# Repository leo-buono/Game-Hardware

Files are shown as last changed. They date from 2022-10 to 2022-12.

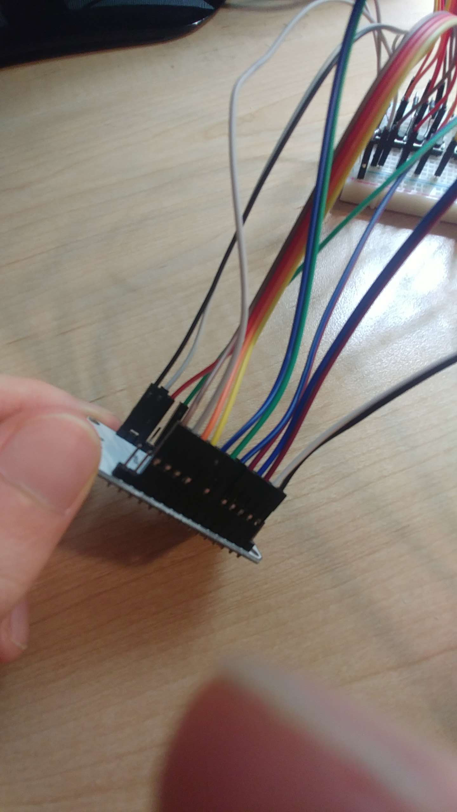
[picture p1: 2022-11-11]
Assignment 3/Images of Device and Electronics/Electronics 2.jpg

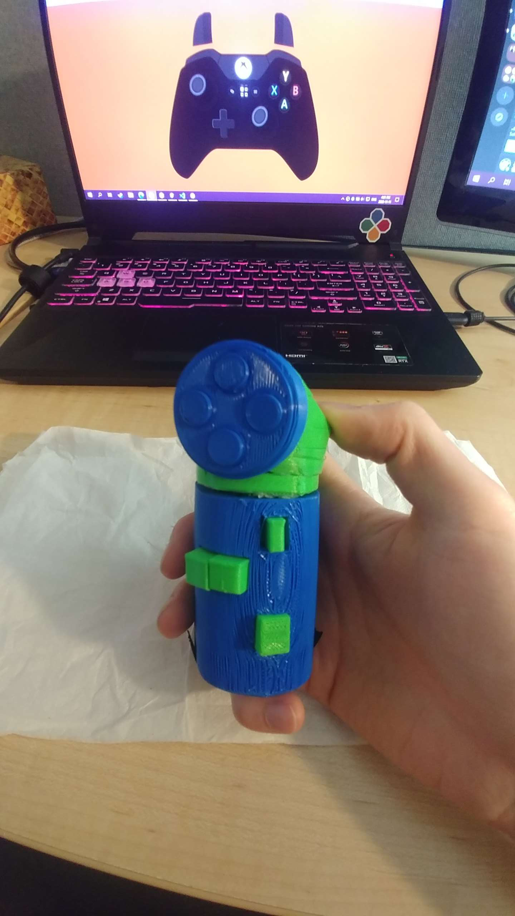
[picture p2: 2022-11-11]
Assignment 3/Images of Device and Electronics/3D Print 1.jpg

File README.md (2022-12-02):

# Game-Hardware
For the purpose of Game Hardware course at OTU (Team Name - SoftWhere?)

**Members & Roles:**   
1. Jonathan Jay - 100743575   
   - Prototyper 
2. Matthew McPherson - 100757379 
   - Designer  
3. Léo Buono - 100748457  
   - Programmer  

**Contributions:**    
     Jonathan Jay:           Created test Unity program, prepared model in slicer, created technical drawings and exploded view animation, QFD and SUS Analysis, and constructed controller.           
     Matthew McPherson:    Catalogued all information about the controllers develeopment, created pitch presentation, constructed controller, wrote report, and general support and design advice.   
     Léo Buono:            3D printed model, programmed micro controller, wrote literature review, QFD and SUS Analysis, soldered and constructed controller.  

**Progression:**   
Final iteration has been created, 3D printed and constructed.    

**Videos**  
Final Project Overview: https://youtu.be/Jnym4vkfmT4  
Exploded View: https://youtu.be/CayruH1D1og  
Assembley: https://youtu.be/mAC65vVBCyk  

**Past Assignment ReadMe Archive**  

**Assignment 3 ReadMe Archive:**     
    
**Contributions:**    
     Jonathan Jay:           Created test Unity program, prepared model in slicer and constructed controller.           
     Matthew McPherson:    Catalogued all information about the controllers develeopment, created pressentation focusing on iteration, and general support and design advice.   
         (would have helped with construction but was unable to due to the Go Bus strike making commuting to campus impossible).    
     Léo Buono:            3D printed model, programmed micro controller and constructed controller.      
 
 **Progression:**   
First 3D print has been created and most functions have been programmed and wired.    
Print Details:  
Grip Print: ~6 hours; 39g blue PLA  
Everything else: (printed with a raft) ~6 hours; 42g green PLA  
  
(14 minute video because of no listed time limit on assignment outline)  
Project Progression Video: https://youtu.be/8G_iirl803k  

**Trello (as of Assignment 3):**  
https://trello.com/b/S6caR4iL/softwhere  
Trello 3
  
**In the Assignment 3 folder you will find:**  
- Images of our 3D print and electronic components  
- Video folder containing Slicer animations and youtube links to said animations  
- A folder containing the 3D print files  
- A folder containing our interactive scene, which is also playable on the github pages (readme there for more details)

**Assignment 2 ReadMe Archive:**  

Contributions:  
     Jonathan Jay:        CAD model, Electronic Schematics  
     Matthew McPherson:   Electronic Schematics, Components List, GrabCAD model search  
     Léo Buono:           Electronic Schematics, Components List, GrabCAD model search  
     
Progress:  
     The project has completed CAD models and is ready to begin physical prototyping via 3D printing. In addition, the project is also entering the phase where we are programming the microcontroller and using breadboard to test components.

In the Assignment 2 folder, you will find:  
-The step file for our controller  
-The technical drawings for our controller and each components  
-A folder called "Schematics" containing our circuit schematics  
-A folder called "Components list" containing a pdf of our component list for electronics  

Notes:  
While creating the exploded view, we ran into issues because we were using Sub-assemblies, and those don't count as extra components and we don't know how to make them do so. This led to us having to un-subassembly all our components which broke our exploding animation. We also found out that all our components' positions are baked into them, which means the technical drawings are not at the correct angle, we didn't know how to fix it so left it as it.

Video Link for Assignment 2 - https://youtu.be/B3a3DfTxIls  

GrabCAD Links:  
https://grabcad.com/library/slide-potentiometers-1  
https://grabcad.com/library/tactile-switches-6mm-tht-1  
https://grabcad.com/library/xbox-one-analog-stick-assembly-1  
https://grabcad.com/library/esp32-devkitc-v4-1

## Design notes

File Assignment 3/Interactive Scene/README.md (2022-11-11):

This Interactive scene is for the purpose of showcasing the functionality of our one handed controller.  
Added through github pages: https://leo-buono.github.io/Game-Hardware/  

In this scene you take control of a character who can move, jump and shoot.  
The goal is to jump from platform to platform without falling and loop around the path. There's also some black boxes along the way that you can use to practice shooting (not required).  
  
Win Condition: make it to the top of the structure.  
Lose condition: fall of the ledge, leads to restart.  
  
Controls:  
Left Stick/WASD - move    
Right Stick/Mouse - aim/move camera    
Left Trigger/Right Mouse - aim mode  
Right Trigger/Left Mouse - shoot  
A/Space - jump

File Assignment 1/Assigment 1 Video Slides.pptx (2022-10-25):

## One-Handed Controller By: SoftWhere

Jonathan Jay - 100743575
Matthew McPherson - 100757379
Léo Buono - 100748457

## Product Description

- We intend to create a one-handed video game controller
- This controller will allow people to use all the same inputs as a standard controller has (2 joysticks, 4 face buttons, d-pad, 2 bumpers, 2 triggers, and start and select), while only requiring one hand to use.
- The goal is to improve the player experience and make it easier to play compared to an able-bodied person.

## Design Thinking Process

## Interview and Digging Deeper

- We interviewed 6 people about their history of using one-handed controllers and what they expected from them.
- All had used a wii-remote and some had used VR controllers.
- Positive over all opinions but criticize the lack of compatibility with all games.
- The interviewees all thought that a one-handed controller should be comfortable and ergonomic.
- Also thought that every part of the controller should be easy to reach without straining your hand

## Reframe the Problem

- We researched past one-handed controllers to gain ideas on how our design could improve on them.
Product Comparison
- There have been many designs in the past:
  - One-handed RPG controller for the NES
  - One-handed controllers with remappable back triggers for ps1
  - One-handed controller with shift button to swap joystick functionality for ps3
  - Various 3D printed snap-on adapters for many controller types
  - Xbox adaptive controller

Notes: Such as joycon merger

## Ideate

- After brainstorming, we came up with 3 ideas:
  - Controller with one joystick that can be shifted using a layout shift button. It will also have 4 face buttons (a,b,x,y), 2 bumpers, 2 triggers, and the shift button on the back of the controller.
  - The use of Gyro to replace one of the analog sticks, removing the need for a second thumb and allowing for both sticks to be in use. Combined with an activation button, (hand, feet, or palm etc.) it can be disabled not requiring the user to keep their hands perfectly still, and this could be used as a recenter button for the Gyro.
  - Utilising a ‘Squeeze’ input. This allows the user to push with their palm in order to give the input. Using this with layout shifting, you’re able to quickly press any combination of buttons, and keep all fingers available for the inputs, as opposed to having a finger dedicated to shifting. There would also be a strap to hold the controller against the upper palm.

## Feedback

- Some feature from our designs were presented to our interviewees for feedback, and 3 we went into discussion with:
  - Turbo Buttons: widely considered helpful, but could affect the play experience.
  - Gyro: potentially helpful but tricky to get right.
  - Shift button: very positively received, but some concern over control complexity.
  - Pedals: potentially useful but unnecessary, problems with wiring to the controller itself (why not go to computer directly).
  - Palm Grip: not well received due to players potentially squeezing the grip unintentionally during tense gameplay moments and un-intuitiveness.

## Final Idea

- The idea that we will be implementing is a controller that will be strapped to your upper palm to allow the usage of every finger. To strap it on, a gear to tighten and loosen the strap will be on the side (see sketch below).
- The buttons on the controller will be as follows:
- Four face buttons on index finger
- Tilt button for bumpers on the middle finger
- Individual triggers on the ring finger
- Layout shift Button on the pinkie finger
- Joystick on the thumb
- Two Menu buttons

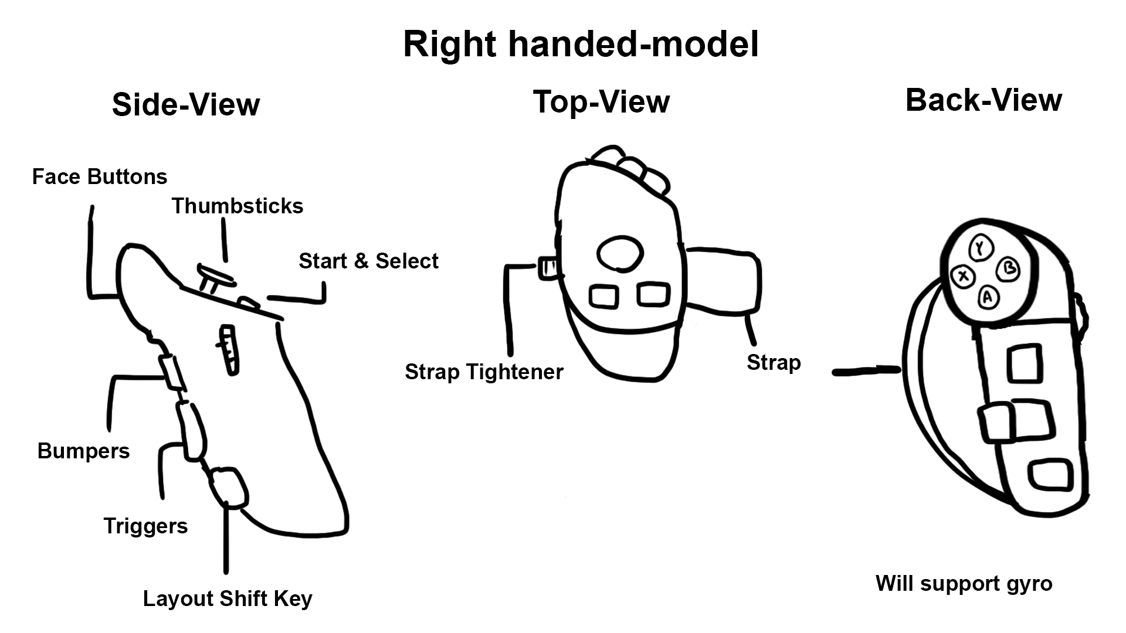
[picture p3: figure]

## Planning

## Planning

- We will be using a trello board to keep track of all tasks

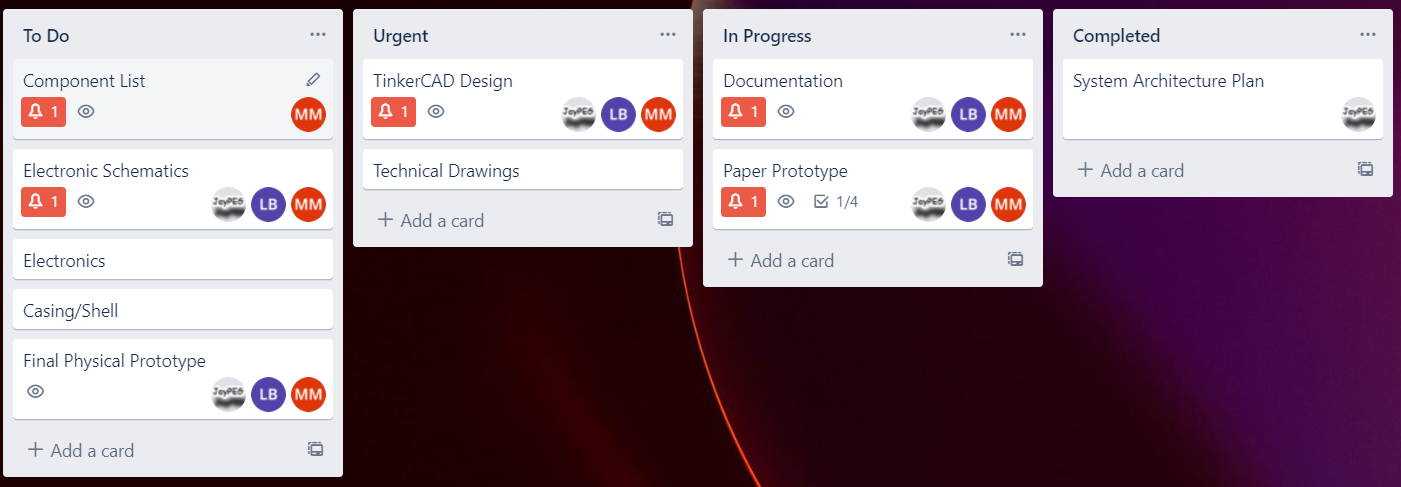
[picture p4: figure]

## The End

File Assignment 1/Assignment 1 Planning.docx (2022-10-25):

- Project description, problem definition:

Context: Playing video games is an activity that can require a wider range of mobility thanks to various controller types like Xbox controllers, or Racing wheels enhancing player experiences.

Issues: However, not all people, and not all players have the physical capability to fully utilise the input device to its fullest potential.

Relevance: This can cause players to struggle to play certain games, and in certain cases make it impossible or nearly impossible to play the desired game using traditional input devices.

Objective: In this project we will be constructing a controller with an aim to allow players with more limited motor functionality to play more of these games that were previously inaccessible, and improve their experiences playing games they may have previously struggled with.

Existing solutions: There are a number of ways that can be implemented to solve the accessibility problem, and there are various available on the market today, such as the Gypard, and many 3D print options such as one where it makes one of the analog sticks accessible in the rear of the controller.

https://gypard.com/

https://www.notebookcheck.net/3D-printed-PlayStation-controller-mod-allows-one-handed-PS4-and-PS5-gaming.597669.0.html

To ask about how viable out ideas are, we asked 6 people some questions:

Questions:

Have you ever used a one-handed controller before (wii remote, vr controller)?

What do you expect from a one-handed controller?

Here are some ideas: etc.

We also engaged in discussions with a few of them:

Pedals sound good, tho consider, Mouth controller (blowtubes https://www.quadstick.com/)

Extra latency

Palm grip: though how do you put it on, wrist as alternative

Turbo does have effect an effect on the game experience

Layout Shift button - only some keys, gyro enable and disable?

Context stuff

Project Description

Definition

Playing video games is an activity that can require a wider range of mobility thanks to the various controller types, like Xbox controllers or Racing wheels, that enhance player experiences. However, not all people, and not all players have the physical capability to fully utilise the input device to its fullest potential. This can result in these players unable to enjoy and play certain games, and in some cases make it impossible or nearly impossible to play the desired game using traditional input devices.

There are a number of tools that can be utilized to mitigate the problem, and various are available on the market today, such as the Gypard and multiple 3D print options, like one that connects one of the analog sticks to another on the rear of the controller, allowing the player to use any surface, such as their thigh to operate one of the analog sticks.

The techniques others have come up with to increase usability are diverse, and include making the controller hardware customizable, like with the Xbox Adaptive Controller and a patented flat controller concept (patent expired) that puts the various inputs within a finger’s reach. Both require being placed on a stable surface to be used properly though, and this makes them not very portable.

In this project, we will be constructing a controller with a goal to allow players with more limited motor functionality to play and enjoy more of the games that were previously inaccessible, and improve their experiences playing them. We will aim to create a handheld design so that people aren’t required to use a table or other flat surface.

Justification

If this problem is not solved, a number of people will remain unable to play and enjoy video games in a comfortable and fun manner. This problem affects people who cannot use two hands playing games that require two. They can be either born this way or lost the hand or function because of an accident.

This problem isn’t specific to just video games, accessibility is a topic discussed in most industries, and many people have attempted solutions in their specific contexts. Not only this, but statistics show that over 3 million people in the USA alone do not have 2 fully functioning hands, which shows just how large of a population could be encountering issues.This does mean that the market for tools that can be used with one hand become important. One example is the JoyKey, it attempts to create a one-handed keyboard for katakana by utilizing flick input keys (joysticks), it is also multipurpose and can be used as a controller (though not effectively one-handed). Another tool is an adaptor for two-handed instruments, such as one for a bass guitar that controls the frets using a foot controller, while allowing the musician to strum with their hand.

Ideation

Design Think

Interview & Digging deeper

We interviewed 6 people about using one-handed controllers. (see appendix for the questions asked)

All six interviewees had used a one-handed controller before, typically a Wii remote and a few had used a VR controller. All of them had positive things to say about the controllers, but criticized their lack of usability for all games. For example: the Wii remote is only one-handed in specific games/contexts. One person also noted that extended use of a one-handed controller can cause cramping.

When asked about what they expected out of a one-handed controller, all of the interviewees were very unanimous with their thoughts. All of them noted that it had to be comfortable to hold and ergonomic. They also thought that the buttons had to be easily accessible without having to reach or strain their hand to access vital controls.

The questions we asked were:

- Have you used a one-handed controller before (VR, Wiimote, etc.)? How did you feel about that experience?
- What do you expect from a one-handed controller?
- Some of the ideas we have for solutions regarding one-handed controllers include:
  - Shift button to reduce the number of total buttons
  - Attachments like foot pedals
  - Gyro to replace directional input
  - Utilizing your palm's grip for an input
  - Turbo and button lock systems
- What are your thoughts on our ideas?

Reframe the problem

Looking through the history of one-handed controllers, there were many different designs, approaches and intentions over the years. Some of the earliest ones were made for the Nintendo Famicom with the purpose of being used not for people with one hand, but rather for RPG games specifically. Much later, controllers were made with the sole purpose of accessibility and inclusion. In 1991, a controller was made for non-analog PS1 games that utilized remappable back buttons to make it more effective and customizable. In 2016, a controller was made that utilized a SHIFT button to swap what the joystick would do. It would cycle between the left stick, right stick and the d-pad. In more recent years, such as 2017, 3D printing your own snap on controller add-ons would become more widespread. This would make it easier to share ideas without the need to manufacture and sell them. In 2018, Microsoft would release the Xbox adaptive controller which was compatible with many other devices which allowed users to create their own set ups to suit their needs more specifically.

Ideate

To think of solutions, we discussed within our group and utilized our interview results and research to create these 3 concepts:

1) Controller with one joystick that can be shifted using a layout shift button. It will also have 4 face buttons (a,b,x,y), 2 bumpers, 2 triggers, and the shift button on the back of the controller.
2) Controller with one joystick and gyro that can be disabled through use of an external input (pedal, grip, etc.) to replace the other joystick. All the standard buttons would be on the back of the controller.
3) Controller with a squeeze input that would be used as a layout shift button, similar to idea 1 but with different button placement and a strap to keep the controller in the hand without requiring it to be gripped, making the input possible

Feedback

We then discussed with 3 of the interviewees their opinions of the features created above (see appendix for the list of potential features). The use of turbo buttons was widely considered useful. Gyro controls were thought to be useful, but to a point and difficult to perfect. The shift button was also thought to be useful but with some concern over complexity. The pedals were considered useful but a little unnecessary. No one really liked the palm grip as players may grip unintentionally during tense sections of games and it would be difficult to learn. Utilizing this feedback and previous information, we created a final concept.

Proposed Concept

The features that were deemed most important were considered when designing the controller.


As seen in Fig. 1, the controller utilizes a vertical grip shape and a strap to hold it against the upper palm, making it harder to drop. The strap is tightened using a gear on the side to make it easier to put on with one hand. At the top of the controller is a joystick and the two menu buttons, on the back is the rest of the inputs. Going downwards, there are the 4 face buttons, the 2 bumpers imputed through a single tilt button, the two triggers side by side, and the shift button that is held when layout shifting.

Layout shifting changes the face buttons into d-pad inputs and activate the gyro for right-stick

System Architecture

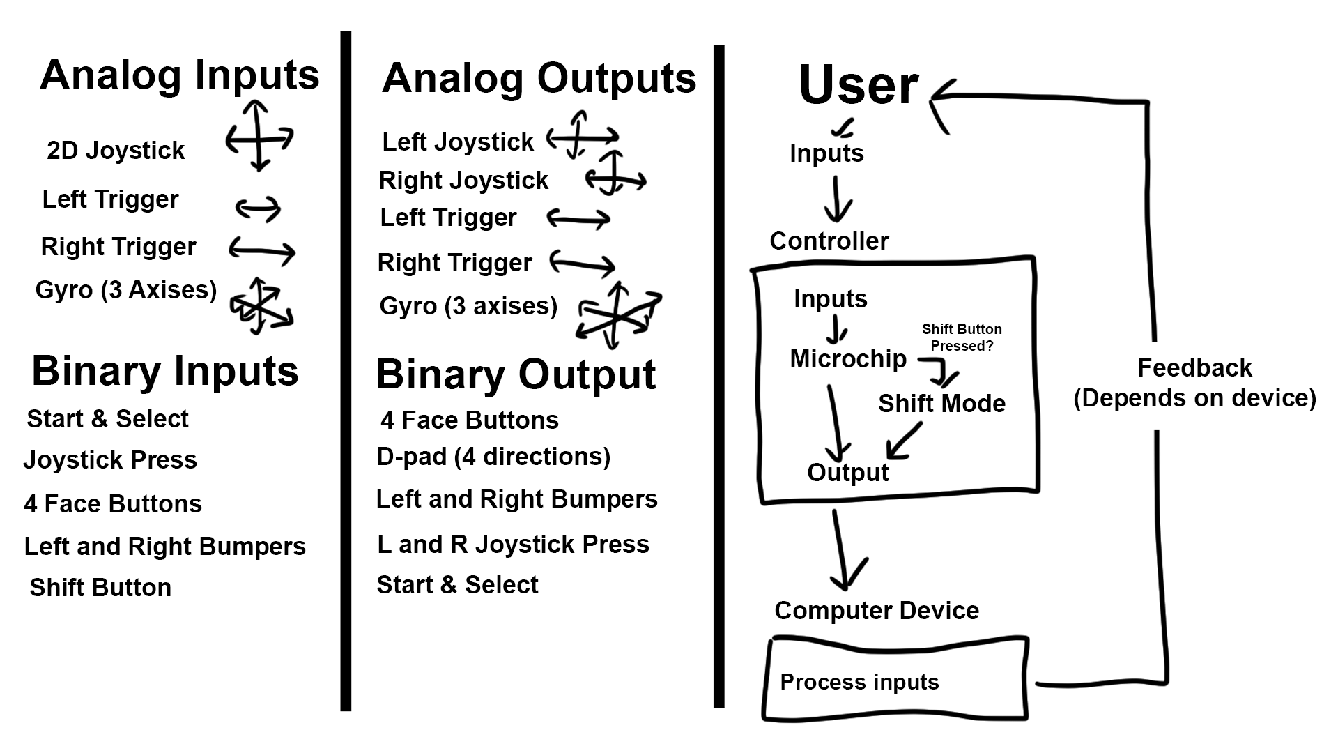
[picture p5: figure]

As seen in Fig. 2, our controller outputs computer readable controller inputs, and takes in less inputs that it outputs. The shift button is the reason for this and is what is used to decide how the other inputs are read and passed through to the computer. This extra step is what allows the controller to output more values than its inputs.

Product Comparison

Timeline of One Handed Controllers:

Source: https://www.oneswitch.org.uk/OS-REPOSITORY/MUSEUM/VARIOUS/CONTROLLERS/ONE-HANDED/ONE-HANDED-GAMING.pdf

1983: Nintendo Famicom Gamepad is created for one handed play.

1989: Ultech Mejin-kun one-hand joystick adapter and ASCII L5 one-hand controller created for RPG and Strategy games specifically.

1997: ASCII created several one-handed controllers for the PS1 for pre analog games. They even had 2 remappable back buttons

2000: Dragonplus RPG ambidextrous controller was released

2006: Nintendo launches the Wii with the Wii remote controller that was used one handed for many games. Unfortunately this was not universal for games that require a Wii nunchuck attachment.

2006: Ben Heck (American Engineer) creates a one-handed controller for the Xbox 360.

2007: Iphone releases with mobile games that commonly only required one thumb to play.

2008: Ben Heck designs the eDimensional Access Controller and releases it for the PS2, PS3 and PC. This wireless controller had swappable control modules.

2010: Evil Controllers sells one-handed controllers in America.

2016: OneSwitch creates a method of converting a PS3 into a one handed controller that has a SHIFT button to change joystick modes.

2017: Julio “Vexelius” Vasquez creates a 3D printed joiner to make 2 switch JoyCons usable with one hand.

2018: Xbox releases the Xbox Adaptive Controller.

2021-2022: Akaki Kuumeri creates advanced 3D printed, snap-on devices to make PS4, PS5, and Xbox controllers one-handed.

Planning

Organized using a Trello board:


Sources

https://gypard.com/

https://www.notebookcheck.net/3D-printed-PlayStation-controller-mod-allows-one-handed-PS4-and-PS5-gaming.597669.0.html

https://www.oneswitch.org.uk/OS-REPOSITORY/MUSEUM/VARIOUS/CONTROLLERS/ONE-HANDED/ONE-HANDED-GAMING.pdf

https://www.ishn.com/articles/97844-statistics-on-hand-and-arm-loss

https://patents.google.com/patent/US20090054146A1/en

JoyKey

https://link.springer.com/chapter/10.1007/978-3-319-58521-5_21

Guitar

https://www.researchgate.net/profile/Jacob-Harrison/publication/325651424_An_Adapted_Bass_Guitar_for_One-Handed_Playing/links/5b1a8bb3a6fdcca67b67050b/An-Adapted-Bas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

Gypard one-handed controller. Gypard. (n.d.). Retrieved September 28, 2022, from https://gypard.com/

ISHN. (2014, January 28). Statistics on hand and arm loss. ISHN RSS. Retrieved September 28, 2022, from https://www.ishn.com/articles/97844-statistics-on-hand-and-arm-loss

One handed gaming - oneswitch.org.uk. (n.d.). Retrieved September 28, 2022, from https://www.oneswitch.org.uk/OS-REPOSITORY/MUSEUM/VARIOUS/CONTROLLERS/ONE-HANDED/ONE-HANDED-GAMING.pdf

Zlatev, D. (2022, February 4). 3D-printed PlayStation controller mod allows one-handed PS4 and PS5 gaming. Notebookcheck. Retrieved September 28, 2022, from https://www.notebookcheck.net/3D-printed-PlayStation-controller-mod-allows-one-handed-PS4-and-PS5-gaming.597669.0.html

Harrison, Jacob, and Andrew P. McPherson. “Adapting the Bass Guitar for One-Handed Playing.” Journal of New Music Research, vol. 46, no. 3, 2017, pp. 270–285., https://doi.org/10.1080/09298215.2017.1340485.

Shizuki, Buntarou, and Shin Takahashi. “JoyKey: One-Handed Hardware Keyboard with 4x3 Grid Slide Keys.” Human Interface and the Management of Information: Information, Knowledge and Interaction Design, 18 May 2017, pp. 266–279., https://doi.org/10.1007/978-3-319-58521-5_21.

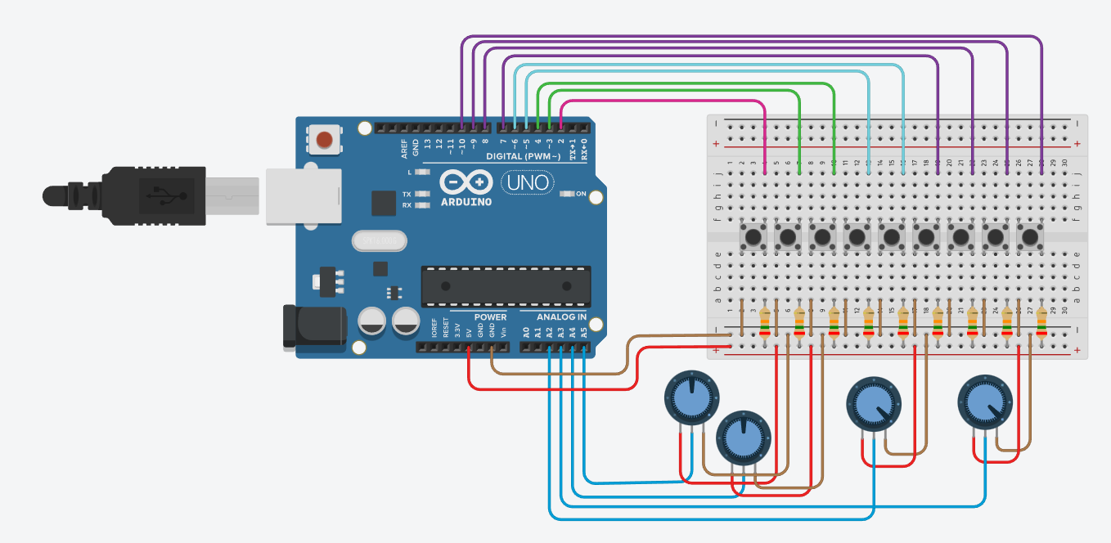
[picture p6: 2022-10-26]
Assignment 2/Schematics/TinkerCAD preview of electronics.png

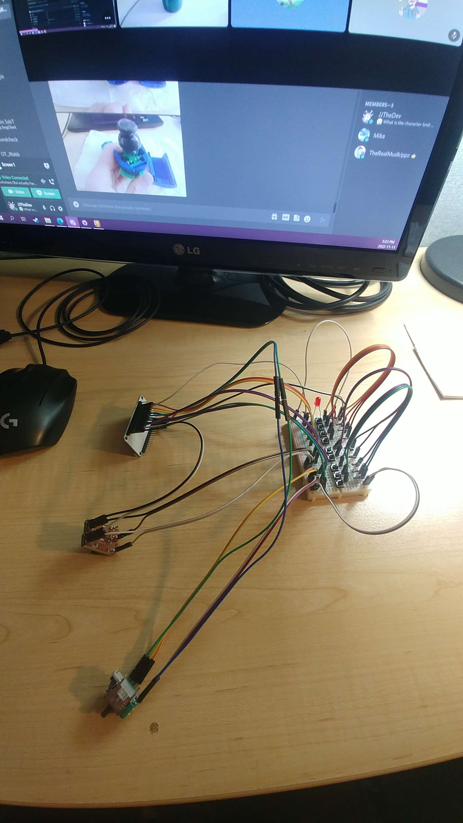
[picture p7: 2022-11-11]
Assignment 3/Images of Device and Electronics/Electronics 1.jpg

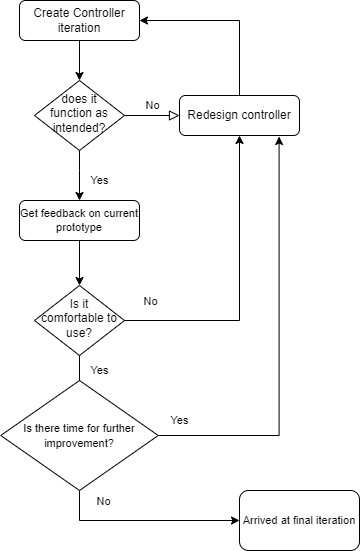
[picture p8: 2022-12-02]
FinalProject/Hardware Flowchart.drawio.png

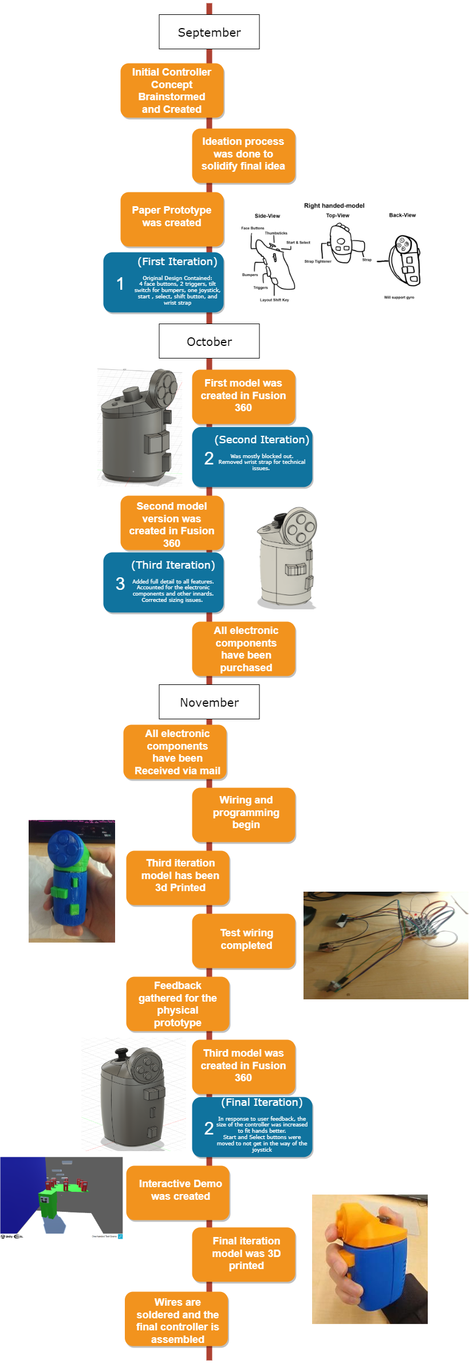
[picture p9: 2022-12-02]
FinalProject/Hardware Timeline.drawio.png

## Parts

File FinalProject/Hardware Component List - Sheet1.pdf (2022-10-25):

Item | Amount | Price | Role | Supplier
ESP32 Micro Controller | 1 | $15.99 | This is necessary for the prototype. We would rather use theis over an Arduino because size and cost. It also has built in bluetooth and wifi. | https://www.amazon.ca/Development-Wireless-Bluetooth-Module-ESP32-D0WDQ6/dp/B07KTV2RRM
Slide Potentiometer | 2 | $2.32 x 2 ($4.64) | These will be used for the controllers triggers. | https://www.digikey.ca/en/products/detail/bourns-inc/PTA1543-2010CIB103/3781161
Jumper Wires | 1 | $8.99 | testing puposes | https://www.amazon.ca/dp/B07GD2BWPY
Analog Joystick (4 Pack) | 1 | $6.79 | One of these is required to make our joystick. | https://www.amazon.ca/RGEEK-Analog-Joystick-Replacement-Controller/dp/B089PZX8VY
TACT Switch Push Button (50 Pack) | 1 | $9.98 | Necessary for our nine buttons. | https://www.amazon.ca/Gikfun-6x6x5mm-Switch-Arduino-EK1019C/dp/B06Y6DDG8K
Springs (50 Pack) | 1 | $11.88 | To push triggers and shift key outwards when not being pressed. Potentially used for other purposes. | https://www.amazon.ca/Metal-Compression-Spring-Silver-0-5x5x25mm/dp/B07P9QCB8M

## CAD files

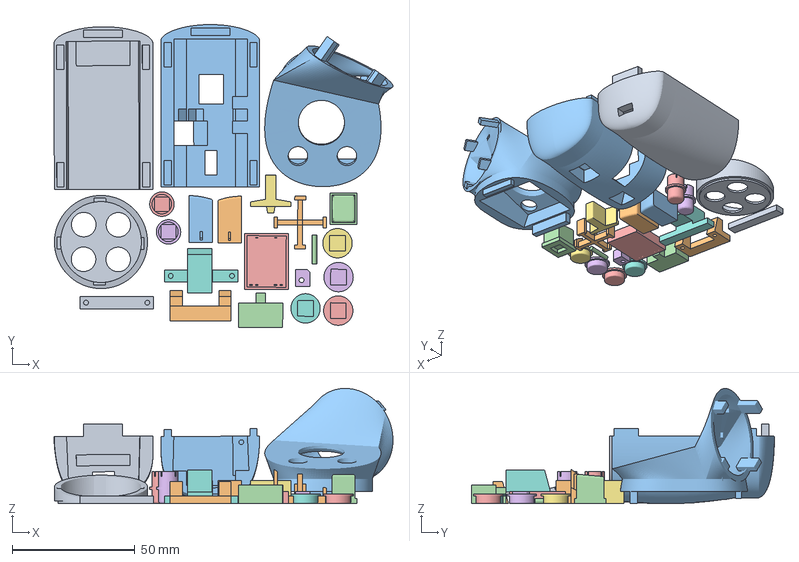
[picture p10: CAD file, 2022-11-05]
Assignment 3/Print files/Controller v2 seperated.3mf
138.4 x 123.6 x 47.0 mm
Controller v2 v69.3mf
Controller v2 v69.3mf(1)
Controller v2 v69.3mf(2)
Controller v2 v69.3mf(3)
Controller v2 v69.3mf(4)
Controller v2 v69.3mf(5)
Controller v2 v69.3mf(6)
Controller v2 v69.3mf(7)
Controller v2 v69.3mf(8)
Controller v2 v69.3mf(9)
Controller v2 v69.3mf(10)
Controller v2 v69.3mf(11)
Controller v2 v69.3mf(12)
Controller v2 v69.3mf(13)
Controller v2 v69.3mf(14)
Controller v2 v69.3mf(15)
Controller v2 v69.3mf(16)
Controller v2 v69.3mf(17)
Controller v2 v69.3mf(18)
Controller v2 v69.3mf(19)
Controller v2 v69.3mf(20)
Controller v2 v69.3mf(21)

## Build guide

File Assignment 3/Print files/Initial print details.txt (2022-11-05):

by JJ,
Estimated time according to Cura: 11:49 hours
30.60 distance
Gradual infill enabled (90%)

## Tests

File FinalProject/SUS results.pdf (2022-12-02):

Q1 | Q2 | Q3 | Q4 | Q5 | Q6 | Q7 | Q8 | Q9 | Q10
Strongly Disagree | 0 | 2 | 0 | 6 | 0 | 5 | 1 | 1 | 0 | 2
Disagree | 1 | 4 | 3 | 1 | 0 | 5 | 2 | 7 | 2 | 3
Neutral | 5 | 2 | 3 | 2 | 0 | 1 | 5 | 2 | 3 | 2
Agree | 4 | 2 | 3 | 1 | 6 | 0 | 1 | 0 | 5 | 3
Strongly Agree | 1 | 1 | 2 | 1 | 5 | 0 | 2 | 1 | 1 | 1
0% | 20% | 40% | 60% | 80% | 100%

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
Strongly Disagree | Disagree | Neutral | Agree | Strongly Agree

Paticipant | Q1 | Q2 | Q3 | Q4 | Q5 | Q6 | Q7 | Q8 | Q9 | Q10

I think that I would like to use this system frequently I found the system unnecessarily complex I thought the system was easy to use I think that I would need the support of a technical person to be able to use this system I found the various functions in this system were well integrated I thought there was too much inconsistency in this system I would imagine that most people would learn to use this system very quickly I found the system very cumbersome to use I felt very confident using the system I needed to learn a lot of things before I could get going with this system Score
1 | 3 | 2 | 3 | 1 | 4 | 1 | 3 | 3 | 3 | 3 | 65 65.68182
2 | 3 | 2 | 3 | 3 | 5 | 2 | 3 | 2 | 2 | 4 | 57.5
3 | 3 | 4 | 2 | 1 | 5 | 1 | 2 | 5 | 2 | 3 | 50
4 | 3 | 2 | 4 | 1 | 4 | 1 | 3 | 2 | 4 | 1 | 77.5
5 | 3 | 3 | 4 | 3 | 5 | 3 | 3 | 2 | 4 | 4 | 60
6 | 4 | 4 | 2 | 4 | 4 | 2 | 2 | 2 | 3 | 4 | 47.5
7 | 2 | 3 | 3 | 1 | 4 | 2 | 3 | 3 | 3 | 2 | 60
8 | 5 | 5 | 5 | 5 | 5 | 2 | 4 | 2 | 4 | 2 | 67.5
9 | 4 | 1 | 5 | 1 | 4 | 2 | 5 | 1 | 5 | 2 | 90
10 | 4 | 1 | 4 | 1 | 4 | 1 | 5 | 2 | 4 | 1 | 87.5
11 | 4 | 2 | 2 | 2 | 5 | 1 | 1 | 2 | 4 | 5 | 60

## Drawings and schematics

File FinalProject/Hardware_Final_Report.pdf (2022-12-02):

# Creation of Dynamic Input One-Handed Controller with Full Functionality

Matthew McPherson
100757379
Student of Ontario Tech University

Jonathan Jay
100743575
Student of Ontario Tech University

Leo Buono ´
100748457
Student of Ontario Tech University

Abstract—In the gaming world, controllers are required to play video games. These controllers require the use of two hands, however, there are many people who do not have the physical capabilities to use both of their hands. This means that these people cannot play video games of any kind. Due to the lack of accessibility to these people, we were motivated to create a one-handed controller. We aimed to make this controller have all of the capabilities of a standard controller and did so to a certain degree of success. We created and tested several iterations of the controller over the course of 3 months before we decided upon a final version. All in all, the project was successful, but not without issues and mistakes to be learned from.
Index Terms—component, formatting, style, styling, insert
I. INTRODUCTION
In the USA alone, there are at least 3,000,000 who have disabilities in their hands or forearms [1]. Needless to say, there are many people worldwide who are incapable of using both of their hands. In the video game world, all standard controllers require the use of two hands in order to use all of its functions, whether it be buttons, triggers or joysticks. The issue here is that all of the people who are physically incapable of using 2 hands cannot participate in the act of playing video games. In order to be accessible to everyone in the market, an alternative controller needs to exist in order to allow these people to enjoy all the games that everyone else is playing. In order to address this problem, we designed a one-handed controller that has all of the functions of a standard controller. Our main focuses in this project are usability and accessibility. In order to create a more usable and comfortable experience, we decided to create a “shift” button. This allowed us to double up the functions of one input device in order to avoid clutter on the controller. When pressed, it makes the joystick change from the left stick to the right and the face buttons to the dpad. This document will go through our research, methods of development, results and takeaways of this project.

II. LITERATURE REVIEW
When beginning our project, we looked into similar designs via reports and patents. This project is far from the first of its kind when approaching one handed devices, whether it be a human interface or an instrument. One such device was a bass guitar that was designed for one handed play, utilizing a fretting mechanism triggered by the feet and a midi controller in order to fret the notes. A 4x3 keypad that allows for writing Japanese characters by clicking and then flicking. It was something that was adopted into the Apple iPhone, and utilizes a second layer after clicking the first in order to type out the sounds. A patent includes a single handed controller that was placed flat on a table or lap that had modules that could be switched out so the buttons or analog stick could be placed in any slots to make it the most optimal for each individual user. Other options include the Gypard. A Wii nunchuck shaped device with an analog stick that has face buttons and triggers/bumpers alongside gyro to replace the second stick. Designed to play First person shooters. The final option that was looked at was a 3D printed option that would attach to a Dualshock 4 controller. It puts the opposing face buttons and triggers in range of the one hand, and rests on your lap for the opposing stick.

III. METHODS


Fig. 1. Sketches for the controller design.
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

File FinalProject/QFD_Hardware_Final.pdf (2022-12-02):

## QFD: House of Quality

### Project: One-Handed Controller

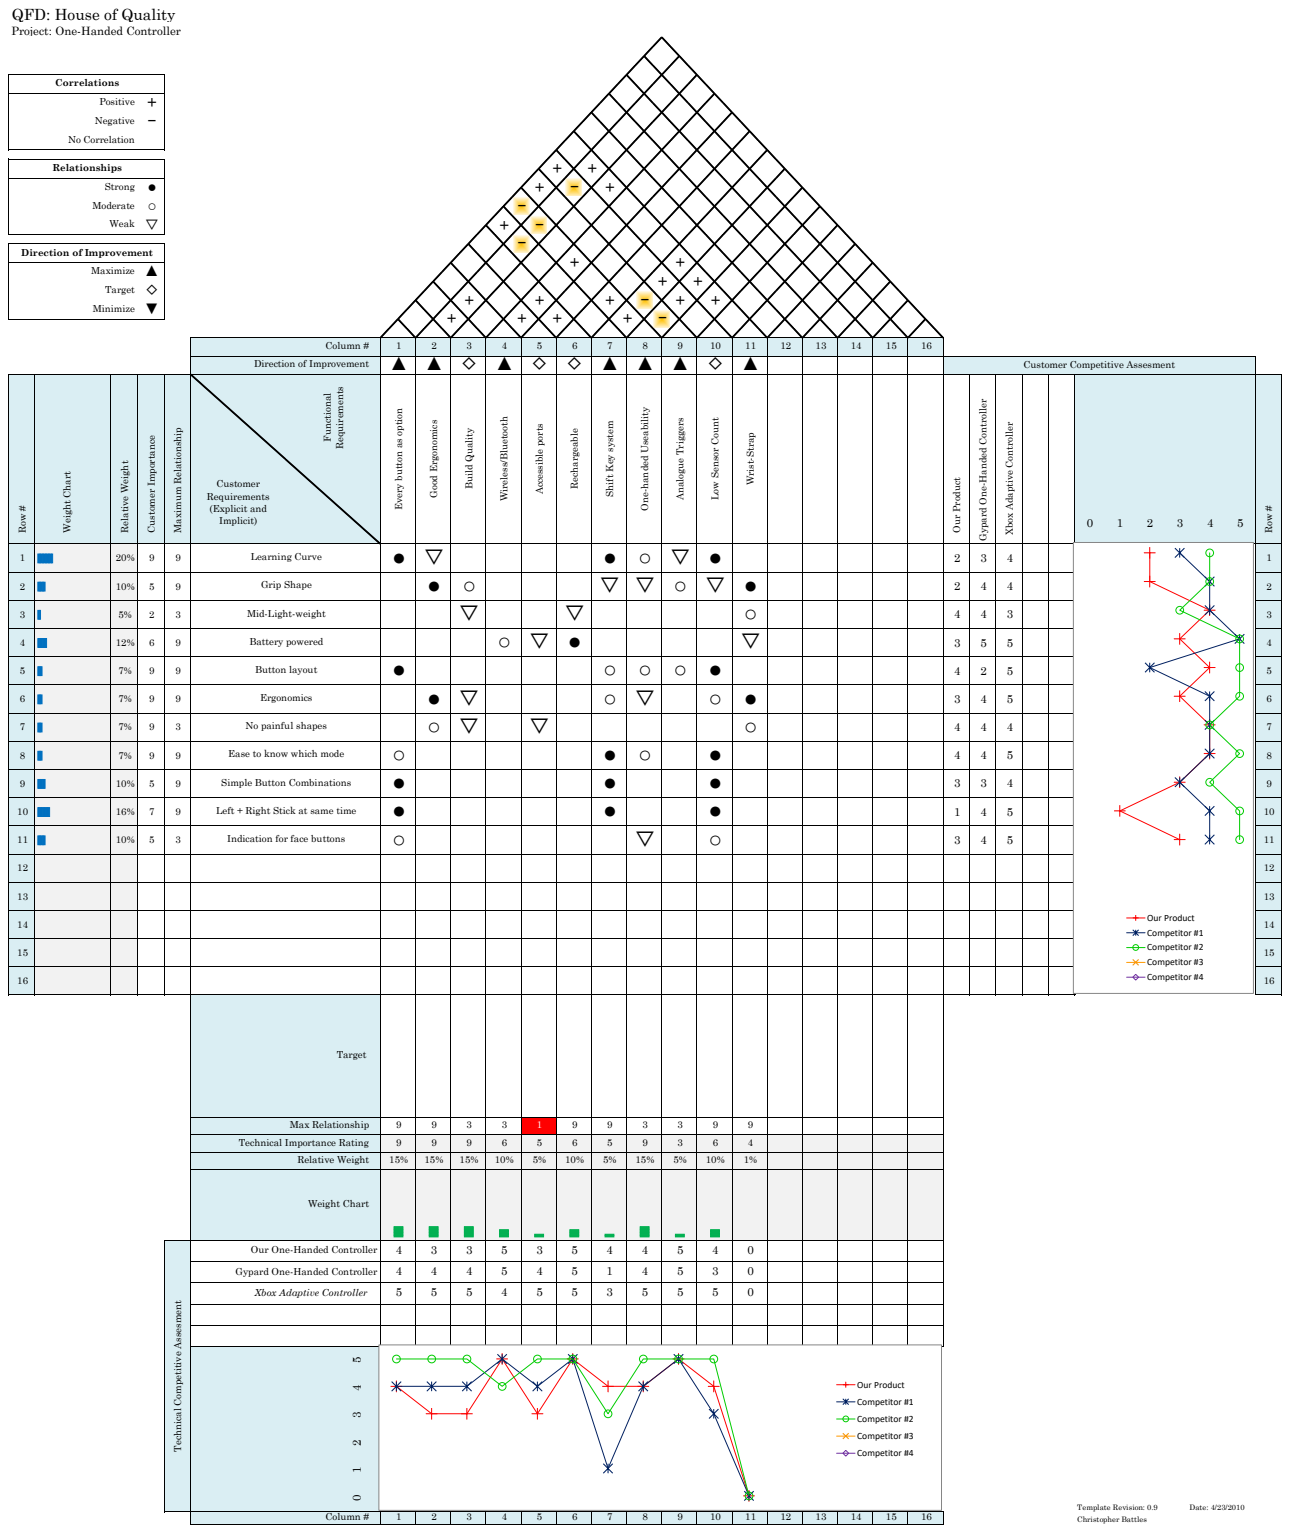
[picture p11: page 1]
Functional; Requirements; Wrist-Strap; Analogue Triggers; Good Ergonomics; Build Quality; Wireless/Bluetooth; Accessible ports; Rechargeable; Row #; Weight Chart; Relative Weight; Customer Importance; Column #; Maximize; Target; Minimize; Correlations; Positive; Negative; No Correlation; Relationships; Strong; Moderate; Weak ▽; Our Product; Template Revision: 0.9; Date: 4/23/2010; Christopher Battles; Maximum Relationship; Our Product Competitor #1 Competitor #2 Competitor #3 Competitor #4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

Direction of Improvement

Direction of Improvement | ▲ | ▲ | ◇ | ▲ | ◇ | ◇ | ▲ | ▲ | ▲ | ◇ | ▲ | | | | | | Customer Competitive Assesment

Column # | 1 | 2 | 3 | 4 | 5 | 6 | 7 | 8 | 9 | 10 | 11 | 12 | 13 | 14 | 15 | 16

Gypard One-Handed Controller

16 3 | || | 5% | 2 | 3 | Mid-Light-weight | | | ▽ | | | ▽ | | | | | ○ | | 4 | 4 | 3 | | 16 Low Sensor Count 3

Every button as option

One-handed Useability

Shift Key system

Xbox Adaptive Controller

Customer Requirements (Explicit and Implicit) | | | | | | | | | | | | | | | | 0 1 2 3 4 5

1 | |||||||||| | 20% | 9 | 9 | Learning Curve | ● | ▽ | | | | | ● | ○ | ▽ | ● | | | 2 | 3 | 4 | | 1

2 | ||||| | 10% | 5 | 9 | Grip Shape | | ● | ○ | | | | ▽ | ▽ | ○ | ▽ | ● | | 2 | 4 | 4 | | 2

4 | |||||| | 12% | 6 | 9 | Battery powered | | | | ○ | ▽ | ● | | | | | ▽ | | 3 | 5 | 5 | | 4

5 | ||| | 7% | 9 | 9 | Button layout | ● | | | | | | ○ | ○ | ○ | ● | | | 4 | 2 | 5 | | 5

6 | ||| | 7% | 9 | 9 | Ergonomics | | ● | ▽ | | | | ○ | ▽ | | ○ | ● | | 3 | 4 | 5 | | 6

7 | ||| | 7% | 9 | 3 | No painful shapes | | ○ | ▽ | | ▽ | | | | | | ○ | | 4 | 4 | 4 | | 7

8 | ||| | 7% | 9 | 9 | Ease to know which mode | ○ | | | | | | ● ○ | | | ● | | | 4 | 4 | 5 | | 8

9 | ||||| | 10% | 5 | 9 | Simple Button Combinations | ● | | | | | | ● ● | | | | | | 3 | 3 | 4 | | 9

10 | |||||||| | 16% | 7 | 9 | Left + Right Stick at same time | ● | | | | | | ● ● | | | | | | 1 | 4 | 5 | | 10

11 | ||||| | 10% | 5 | 3 | Indication for face buttons | ○ | | | | | | | ▽ | | ○ | | | 3 | 4 | 5 | | 11

Target

Max Relationship | 9 | 9 | 3 | 3 | 1 | 9 | 9 | 3 | 3 | 9 | 9

Technical Importance Rating

Weight Chart | 9 | ||||||| 9 | ||||||| 9 | ||||| 6 | || 5 | ||||| 6 | || 5 | 9 | 3 | 6 | 4

Relative Weight | 15% | 15% | 15% | 10% | 5% | 10% | 5% | 15% | 5% | 10% | 1%

Our One-Handed Controller | 4 | 3 | 3 | 5 | 3 | 5 | 4 | 4 | 5 | 4 | 0
Gypard One-Handed Controller | 4 | 4 | 4 | 5 | 4 | 5 | 1 | 4 | 5 | 3 | 0
Xbox Adaptive Controller | 5 | 5 | 5 | 4 | 5 | 5 | 3 | 5 | 5 | 5 | 0

Technical Competitive Assesment

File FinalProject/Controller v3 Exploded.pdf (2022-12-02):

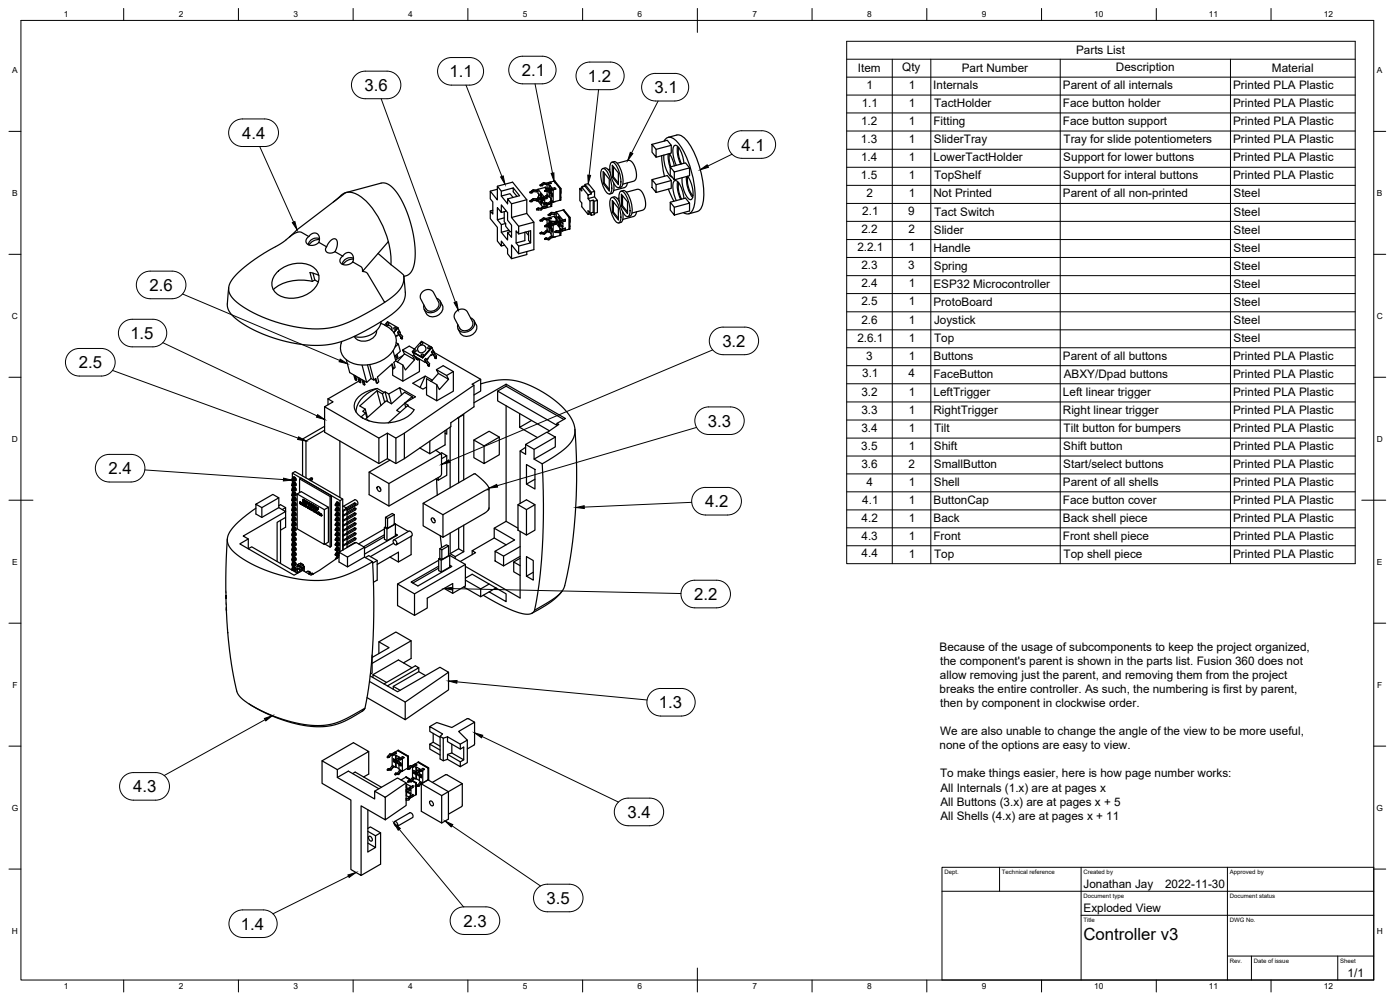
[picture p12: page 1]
Parts List; 12 BACDEFGH; BACDEFGH

Item | Qty 1 | Internals Part Number | Parent of all internals Description | Printed PLA Plastic Material 1

1.1 | 1 | TactHolder | Face button holder | Printed PLA Plastic
1.2 | 1 | Fitting | Face button support | Printed PLA Plastic
1.3 | 1 | SliderTray | Tray for slide potentiometers | Printed PLA Plastic
1.4 | 1 | LowerTactHolder | Support for lower buttons | Printed PLA Plastic
1.5 | 1 1 | Not Printed TopShelf | Parent of all non-printed Support for interal buttons | Printed PLA Plastic 2 Steel

2.1 | 9 | Tact Switch | | Steel
2.2 | 2 | Slider | | Steel
2.2.1 | 1 | Handle | | Steel
2.3 | 3 | Spring | | Steel
2.4 | 1 | ESP32 Microcontroller | | Steel
2.5 | 1 | ProtoBoard | | Steel
2.6 | 1 | Joystick | | Steel
2.6.1 | 1 1 | Buttons Top | Parent of all buttons | Printed PLA Plastic Steel 3

3.1 | 4 | FaceButton | ABXY/Dpad buttons | Printed PLA Plastic
3.2 | 1 | LeftTrigger | Left linear trigger | Printed PLA Plastic
3.3 | 1 | RightTrigger | Right linear trigger | Printed PLA Plastic
3.4 | 1 | Tilt | Tilt button for bumpers | Printed PLA Plastic
3.5 | 1 | Shift | Shift button | Printed PLA Plastic
3.6 | 2 1 | SmallButton Shell | Parent of all shells Start/select buttons | Printed PLA Plastic 4 Printed PLA Plastic

4.1 | 1 | ButtonCap | Face button cover | Printed PLA Plastic
4.2 | 1 | Back | Back shell piece | Printed PLA Plastic
4.3 | 1 | Front | Front shell piece | Printed PLA Plastic
4.4 | 1 | Top | Top shell piece | Printed PLA Plastic

Because of the usage of subcomponents to keep the project organized,
the component's parent is shown in the parts list. Fusion 360 does not
allow removing just the parent, and removing them from the project
breaks the entire controller. As such, the numbering is first by parent,
then by component in clockwise order.

We are also unable to change the angle of the view to be more useful,
none of the options are easy to view.

To make things easier, here is how page number works:
All Internals (1.x) are at pages x
All Buttons (3.x) are at pages x + 5
All Shells (4.x) are at pages x + 11

Dept. | Technical reference | Created by Jonathan Jay 2022-11-30 | Approved by

Document type Exploded View | Document status

Title Controller v3 | DWG No.

Rev. | Date of issue | Sheet 1/1

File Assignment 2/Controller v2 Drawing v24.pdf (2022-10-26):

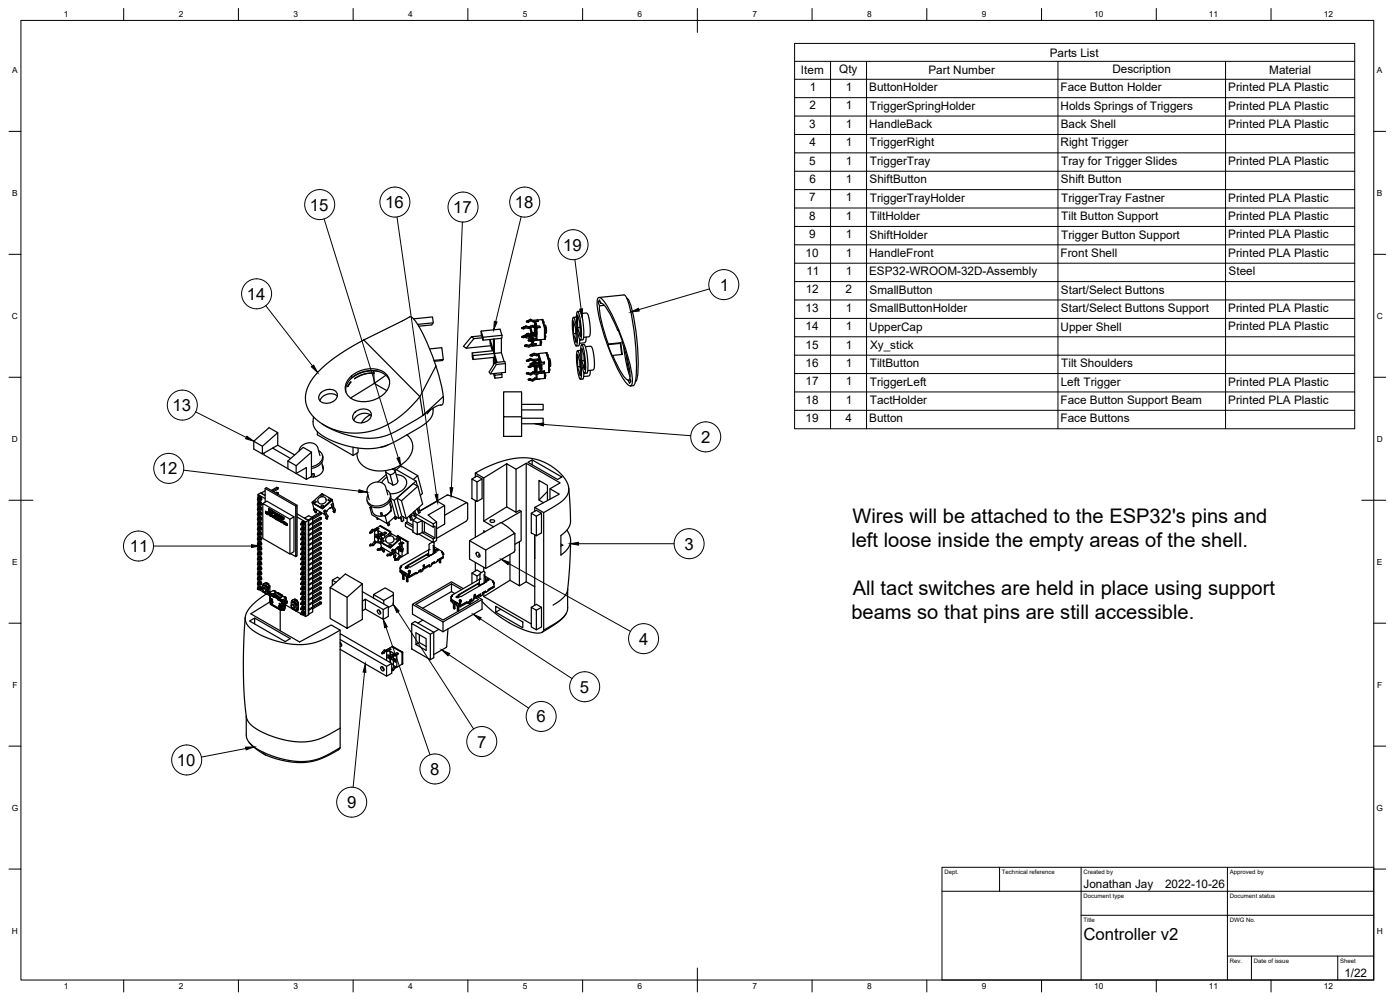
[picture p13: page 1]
Parts List

Item | Qty | Part Number | Description | Material
1 | 1 | ButtonHolder | Face Button Holder | Printed PLA Plastic
2 | 1 | TriggerSpringHolder | Holds Springs of Triggers | Printed PLA Plastic
3 | 1 | HandleBack | Back Shell | Printed PLA Plastic
4 | 1 | TriggerRight | Right Trigger
5 | 1 | TriggerTray | Tray for Trigger Slides | Printed PLA Plastic
6 | 1 | ShiftButton | Shift Button
7 | 1 | TriggerTrayHolder | TriggerTray Fastner | Printed PLA Plastic
8 | 1 | TiltHolder | Tilt Button Support | Printed PLA Plastic
9 | 1 | ShiftHolder | Trigger Button Support | Printed PLA Plastic
10 | 1 | HandleFront | Front Shell | Printed PLA Plastic
11 | 1 | ESP32-WROOM-32D-Assembly | | Steel
12 | 2 | SmallButton | Start/Select Buttons
13 | 1 | SmallButtonHolder | Start/Select Buttons Support | Printed PLA Plastic
14 | 1 | UpperCap | Upper Shell | Printed PLA Plastic
15 | 1 | Xy_stick
16 | 1 | TiltButton | Tilt Shoulders
17 | 1 | TriggerLeft | Left Trigger | Printed PLA Plastic
18 | 1 | TactHolder | Face Button Support Beam | Printed PLA Plastic
19 | 4 | Button | Face Buttons

Wires will be attached to the ESP32's pins and
left loose inside the empty areas of the shell.

All tact switches are held in place using support
beams so that pins are still accessible.

Dept. | Technical reference | Created by Jonathan Jay 2022-10-26 | Approved by

Document type | Document status

Title Controller v2 | DWG No.

Rev. | Date of issue | Sheet

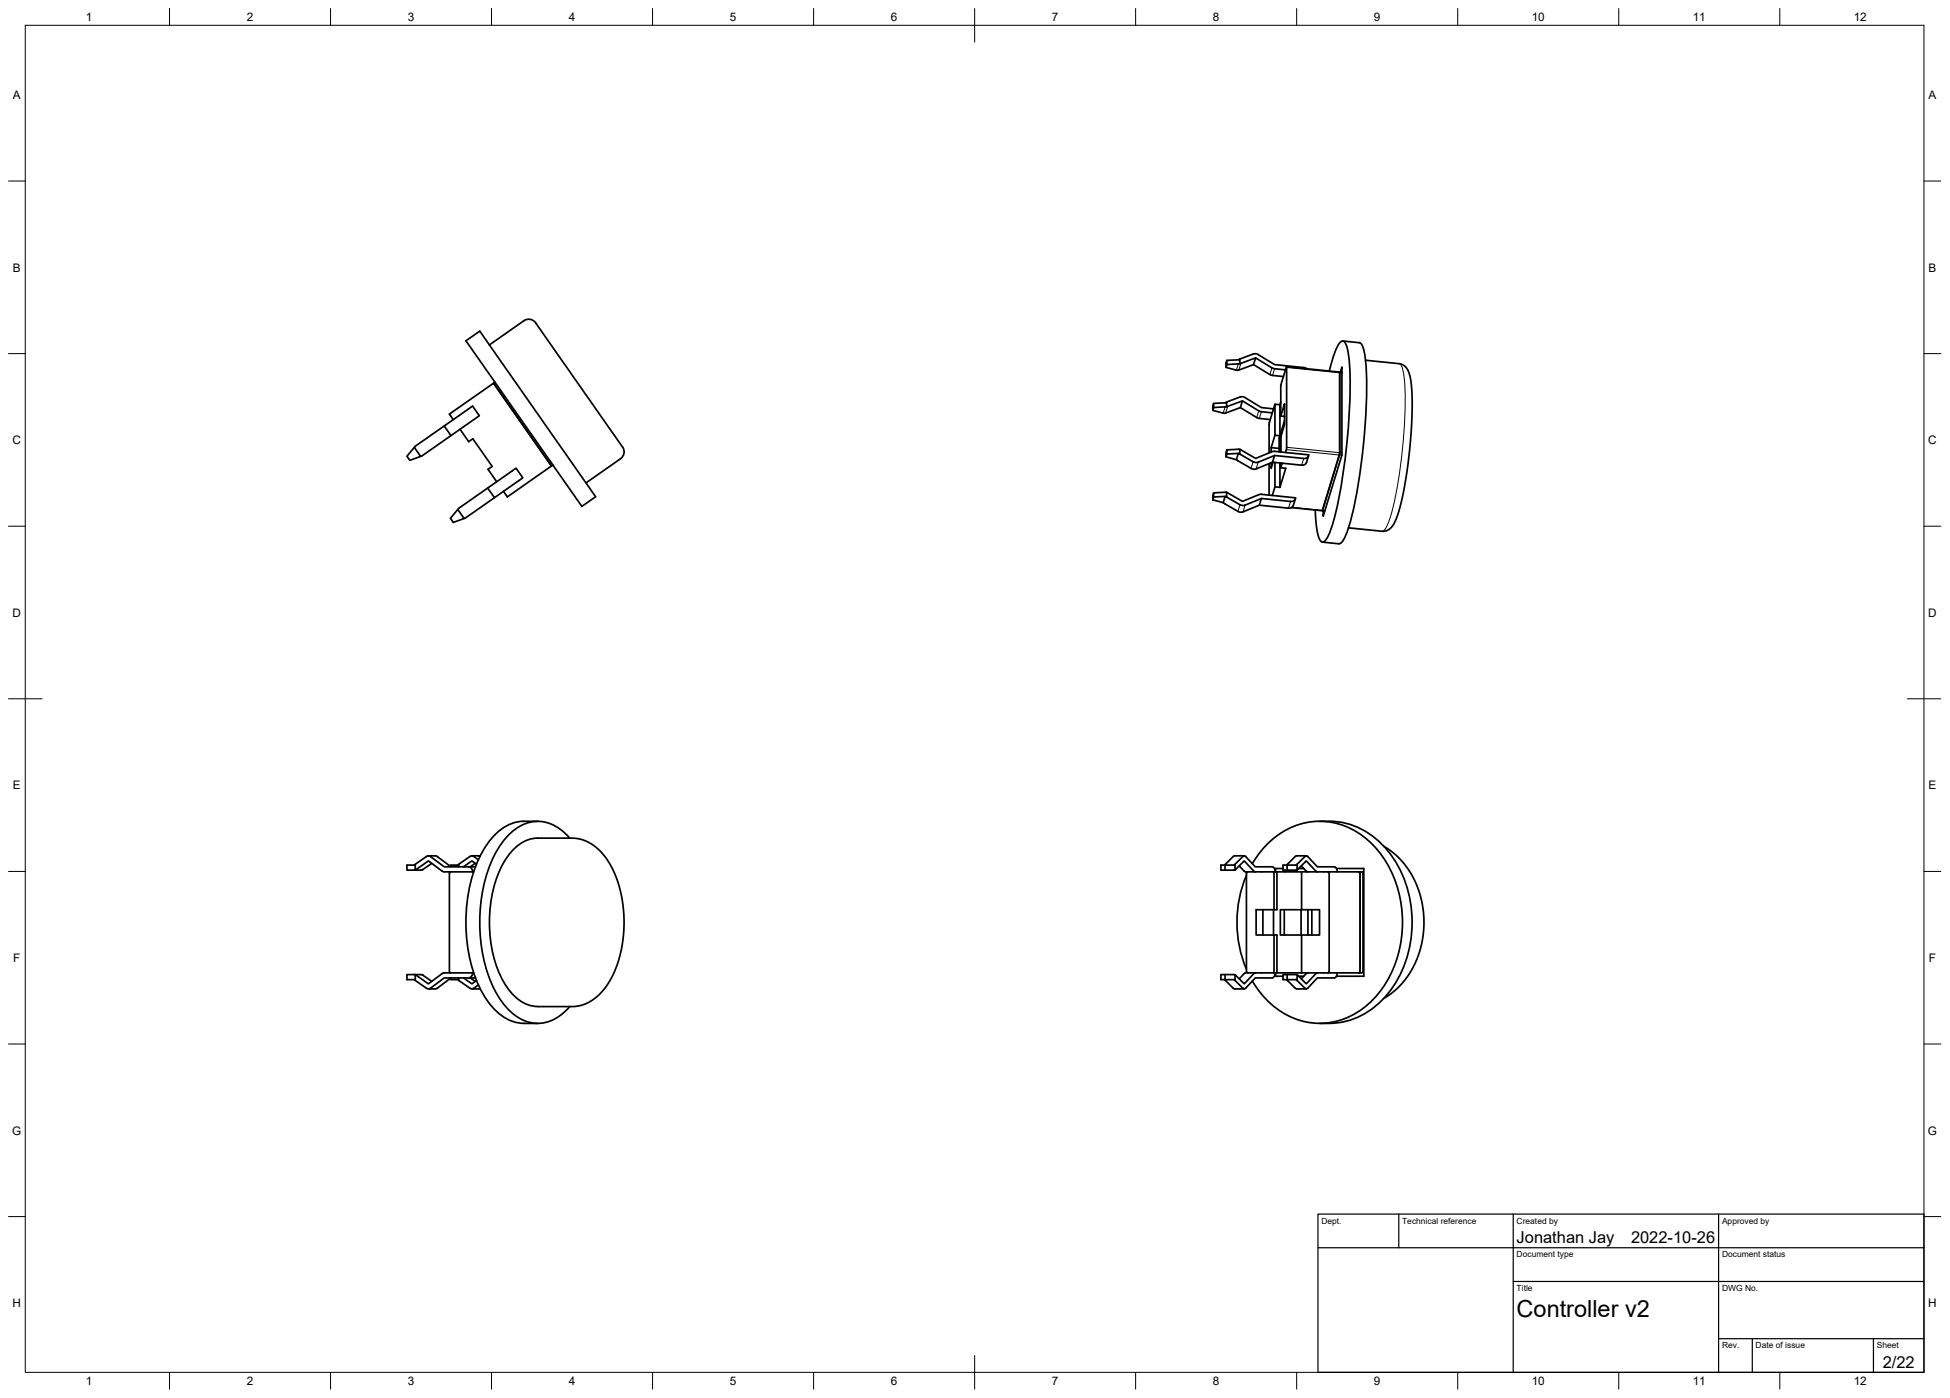
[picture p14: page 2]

Dept. | Technical reference | Created by Jonathan Jay 2022-10-26 | Approved by

Document type | Document status

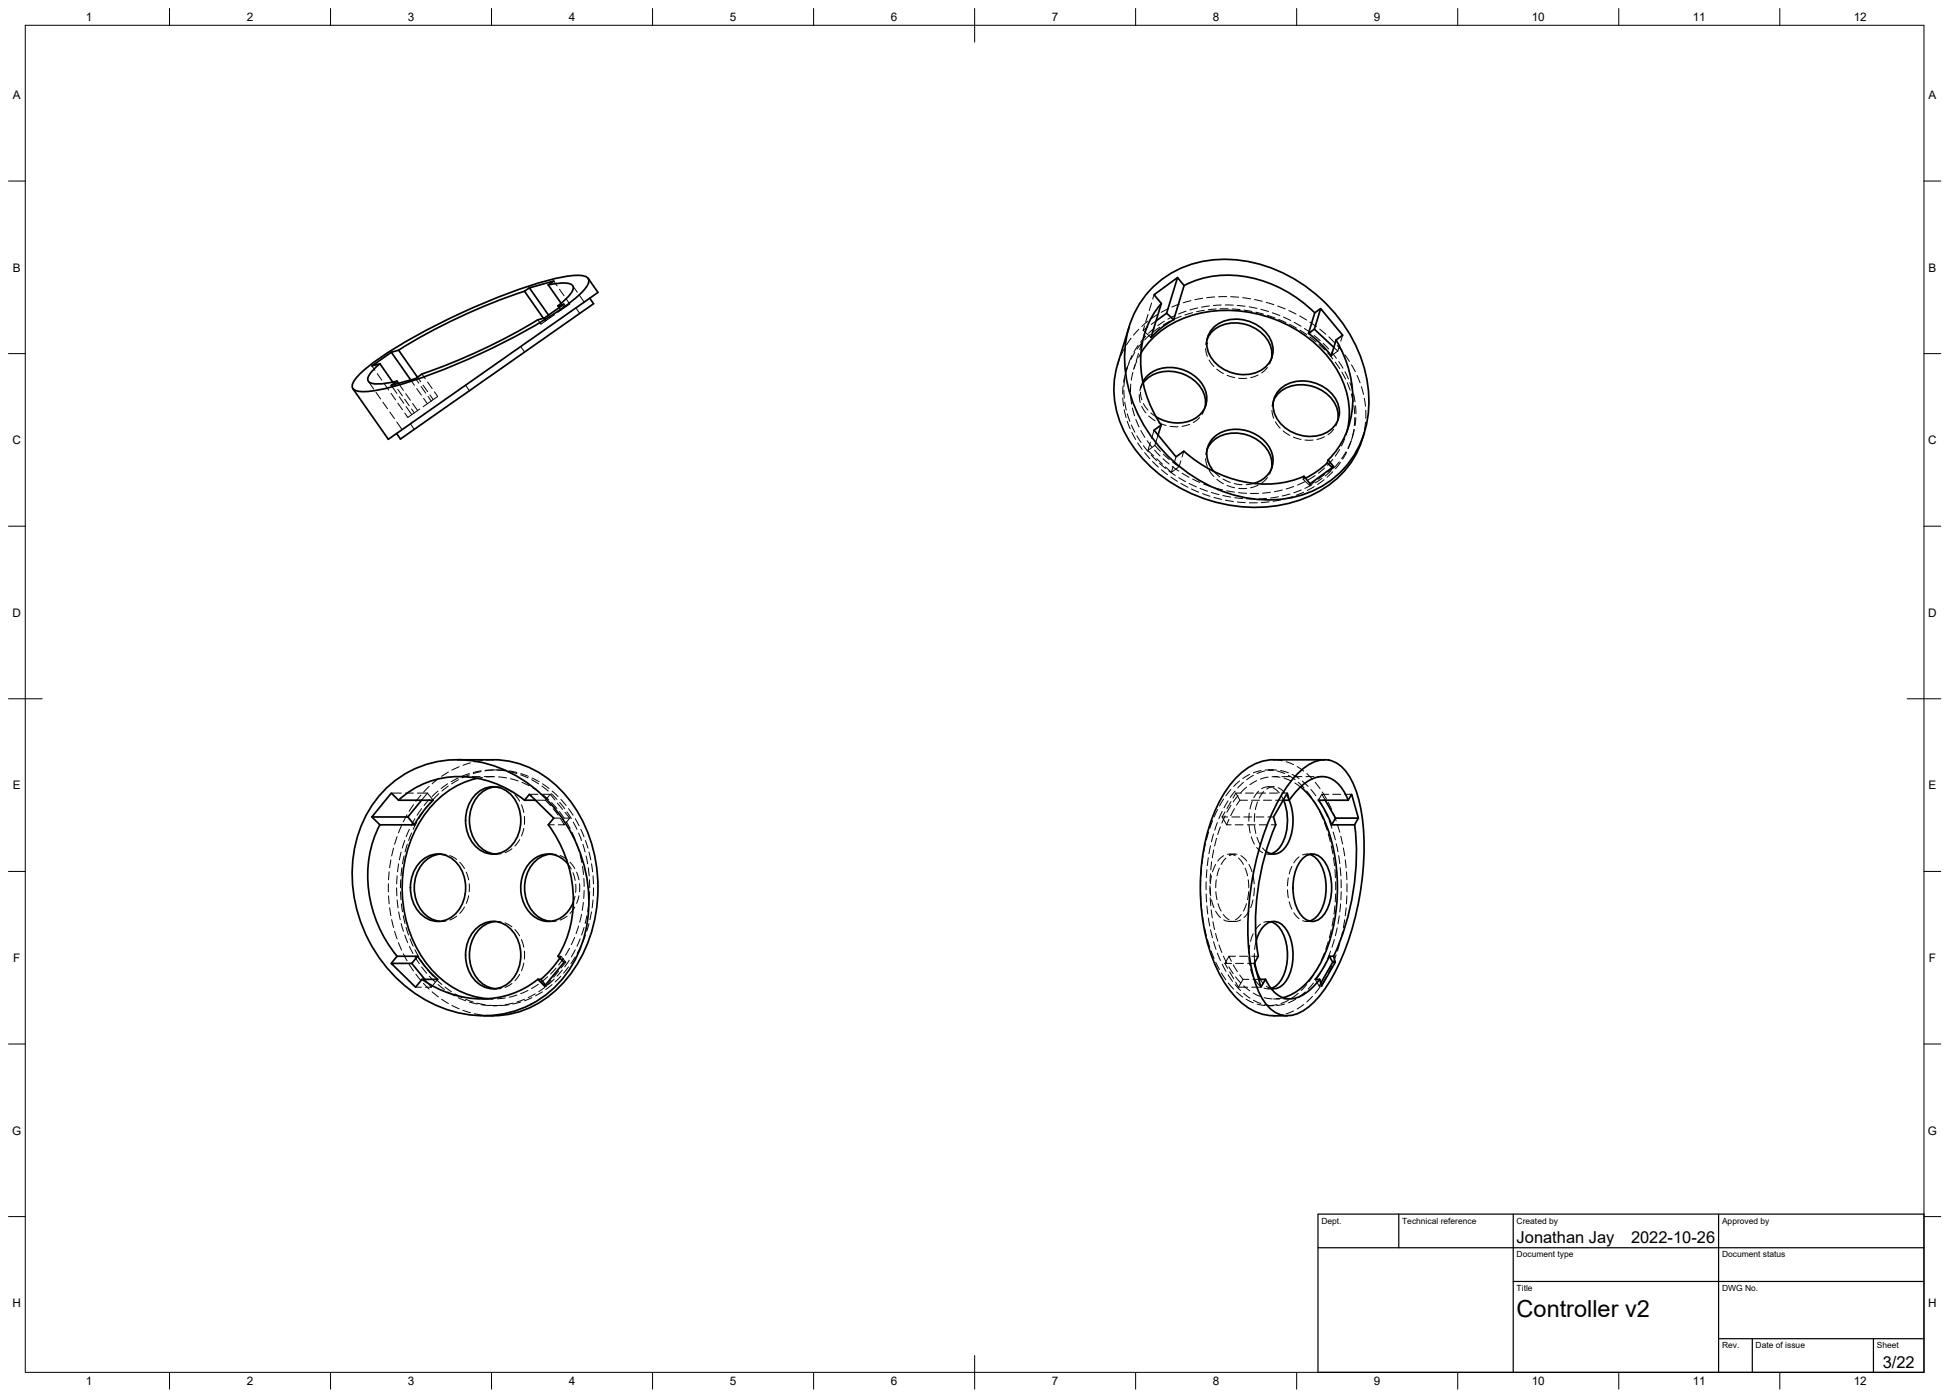
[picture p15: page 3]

Dept. | Technical reference | Created by Jonathan Jay 2022-10-26 | Approved by

Document type | Document status

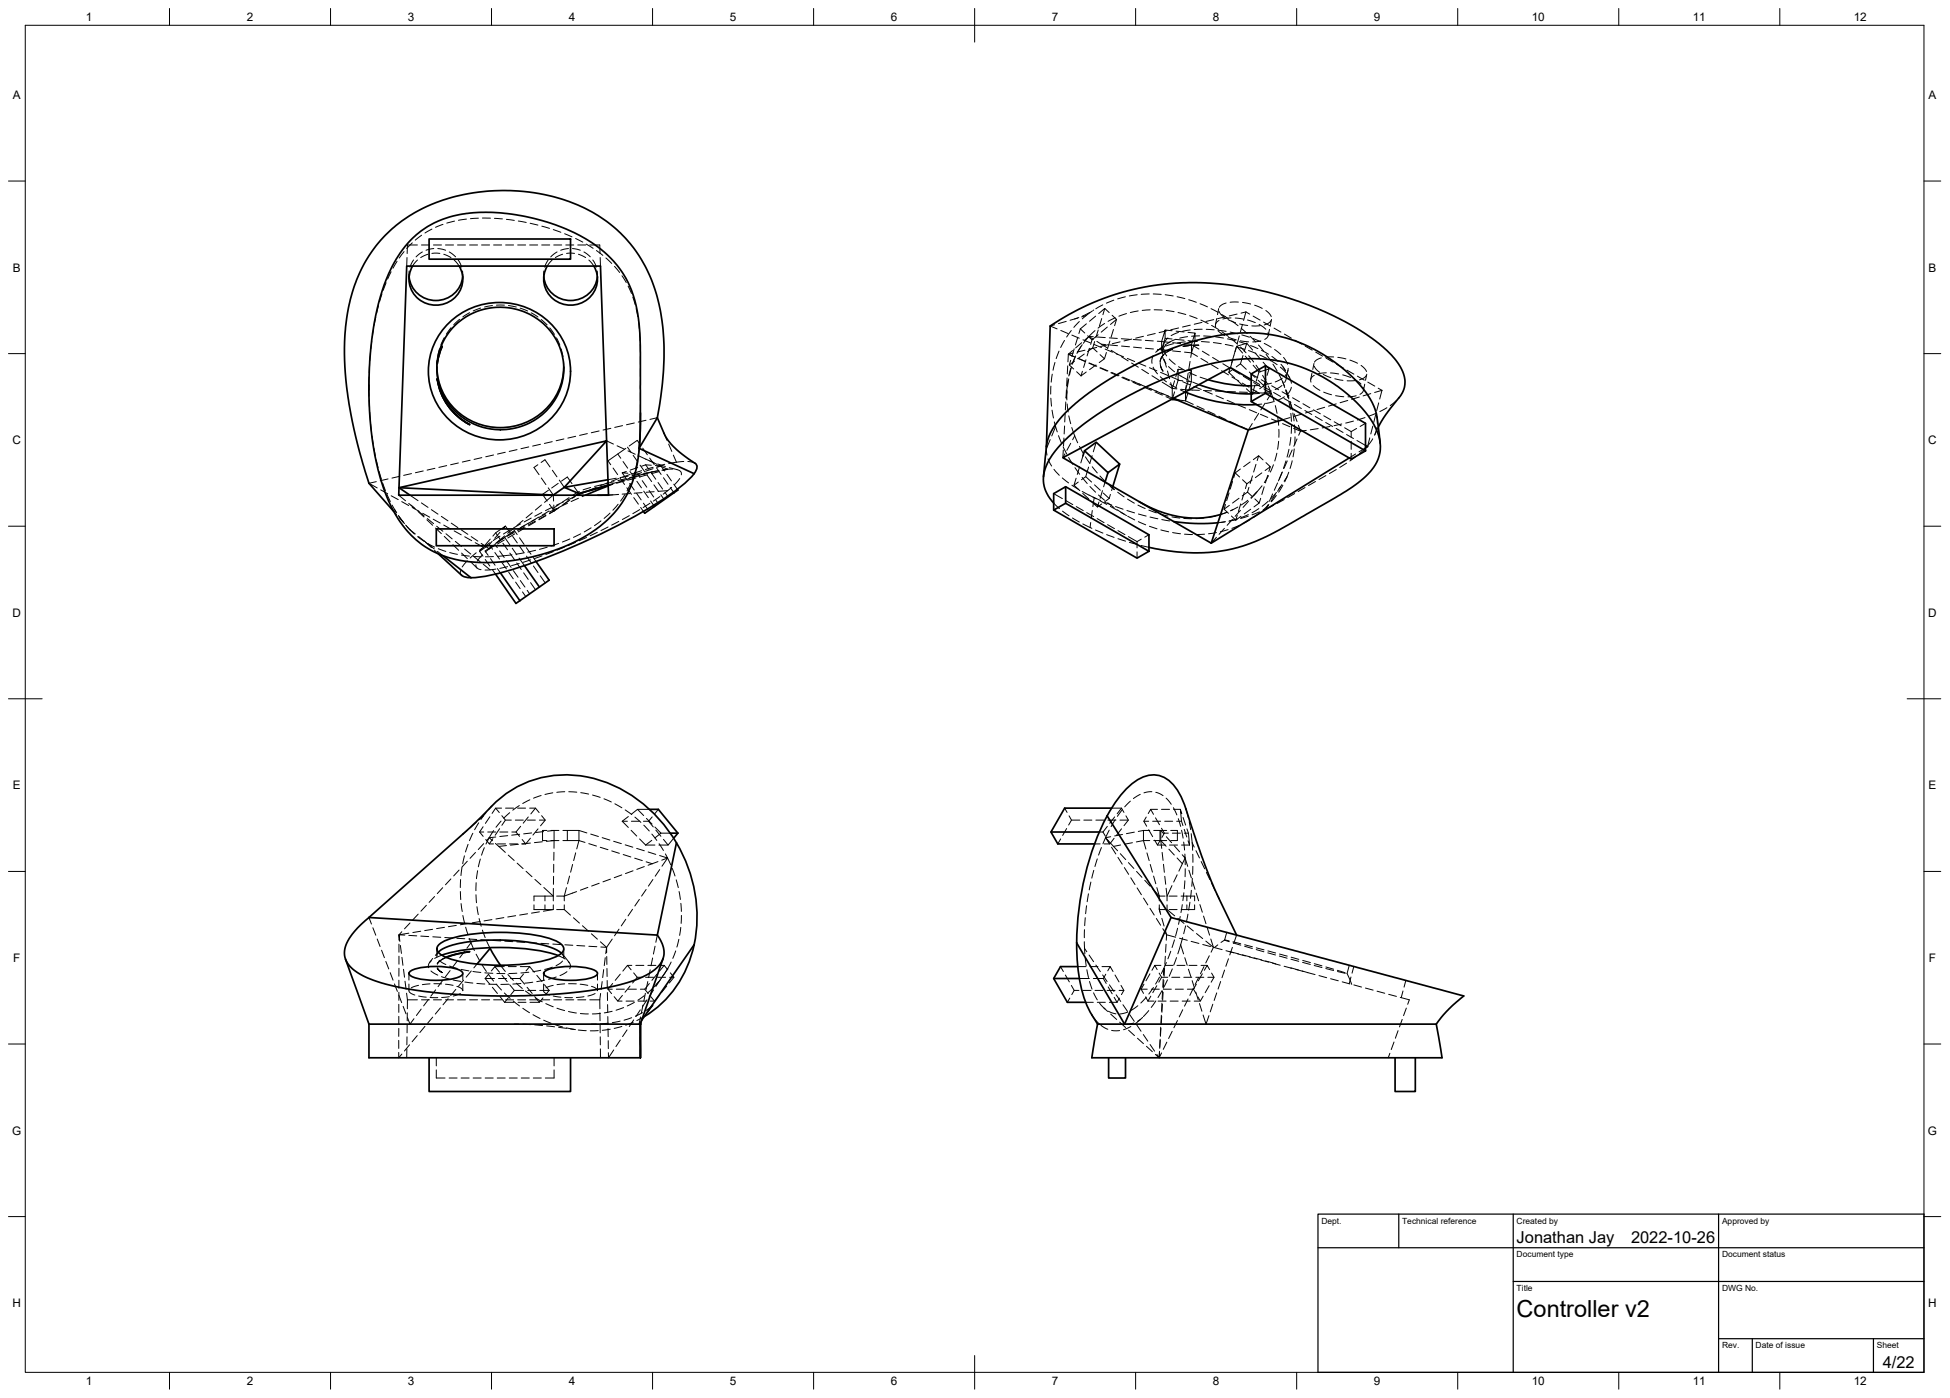
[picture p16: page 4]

Dept. | Technical reference | Created by Jonathan Jay 2022-10-26 | Approved by

Document type | Document status

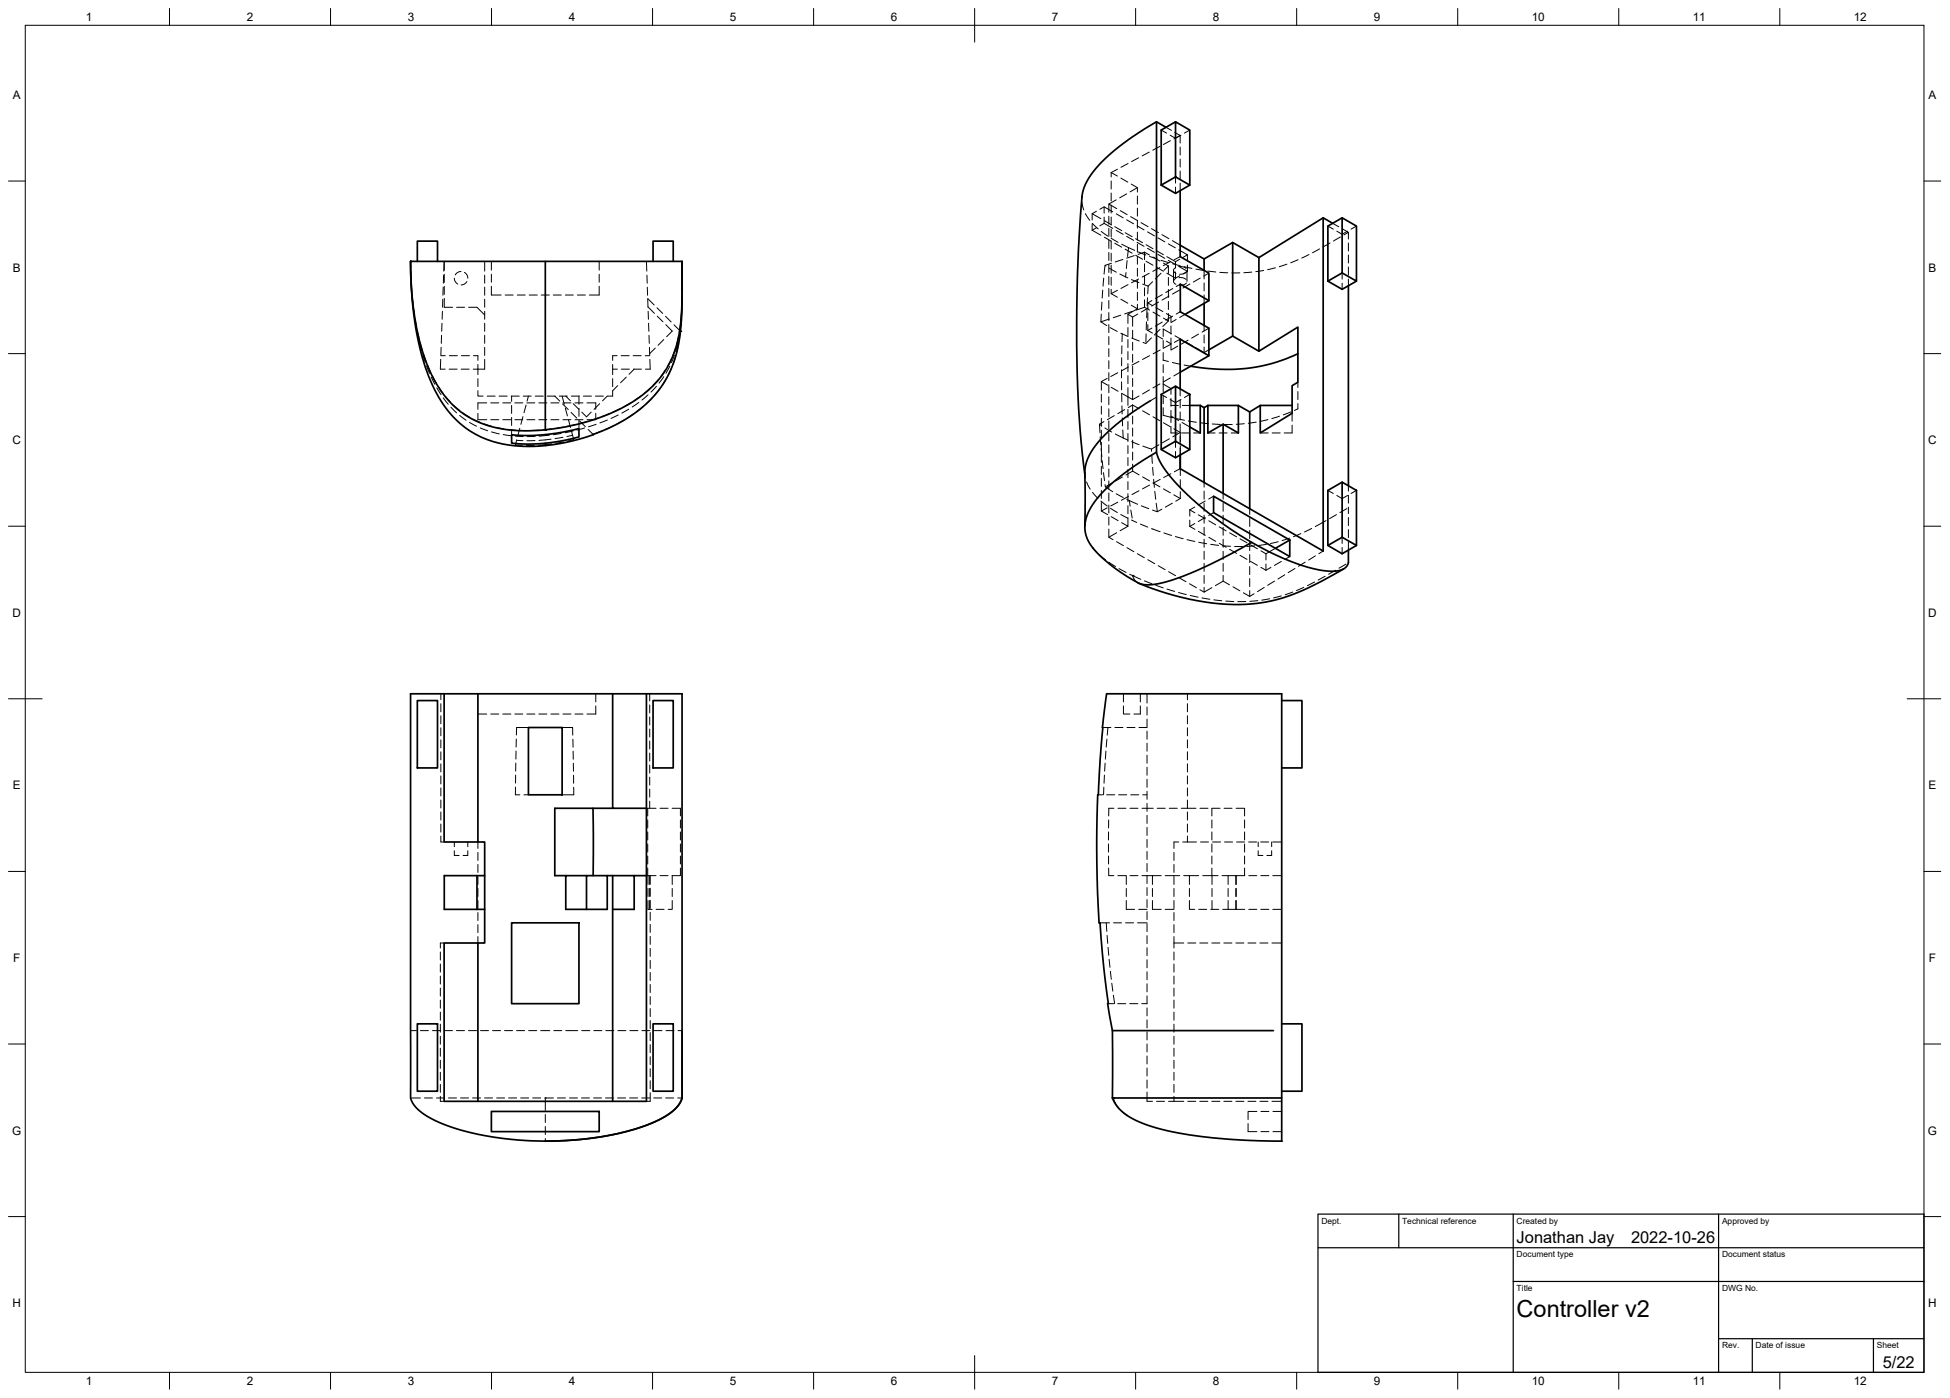
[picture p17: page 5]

Dept. | Technical reference | Created by Jonathan Jay 2022-10-26 | Approved by

Document type | Document status

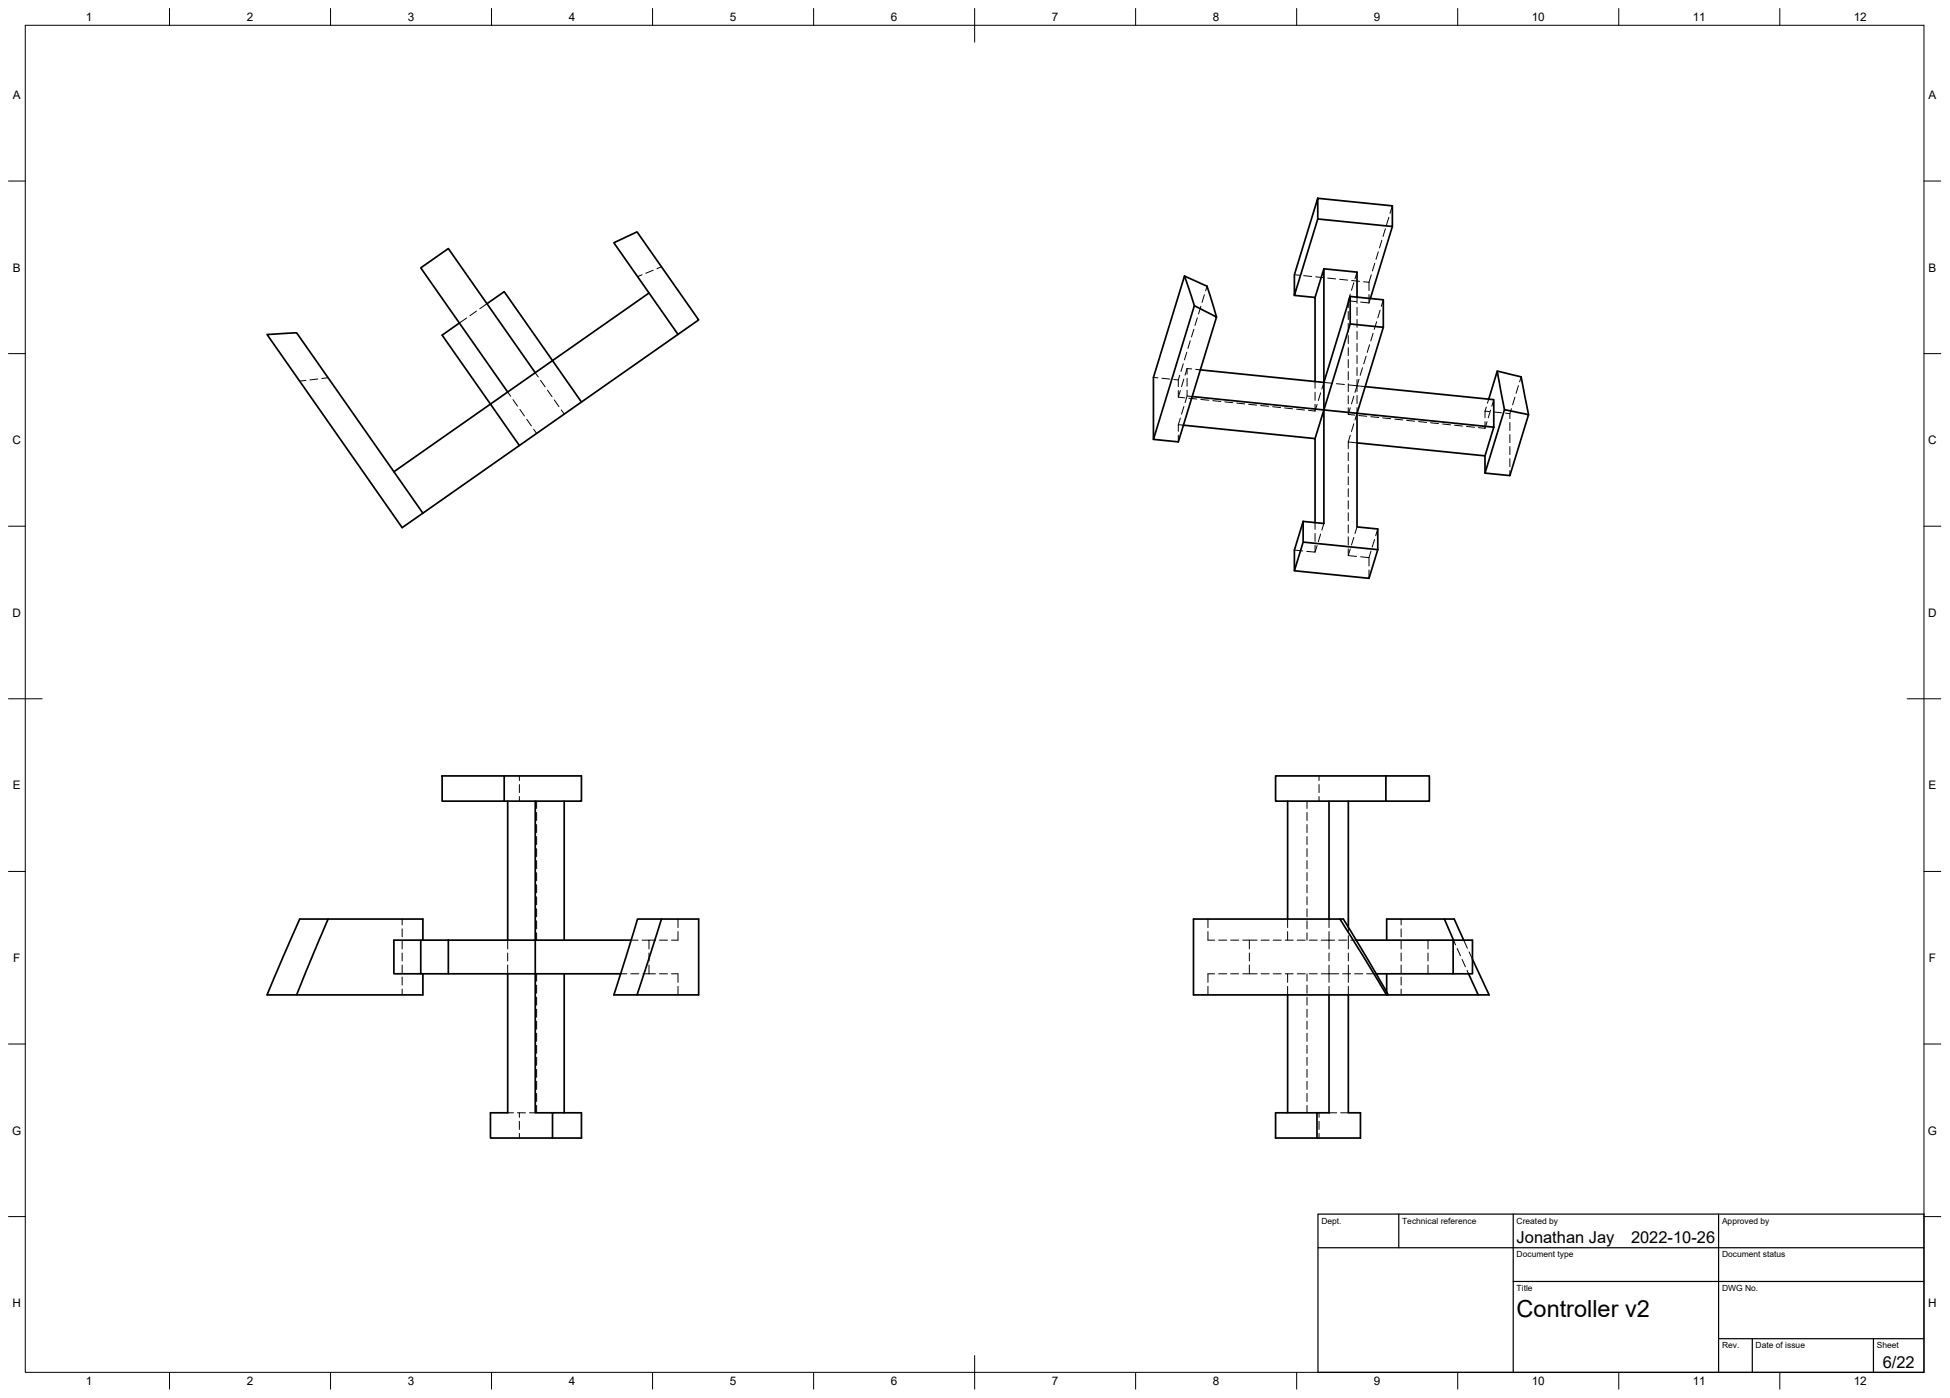
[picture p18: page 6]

Dept. | Technical reference | Created by Jonathan Jay 2022-10-26 | Approved by

Document type | Document status

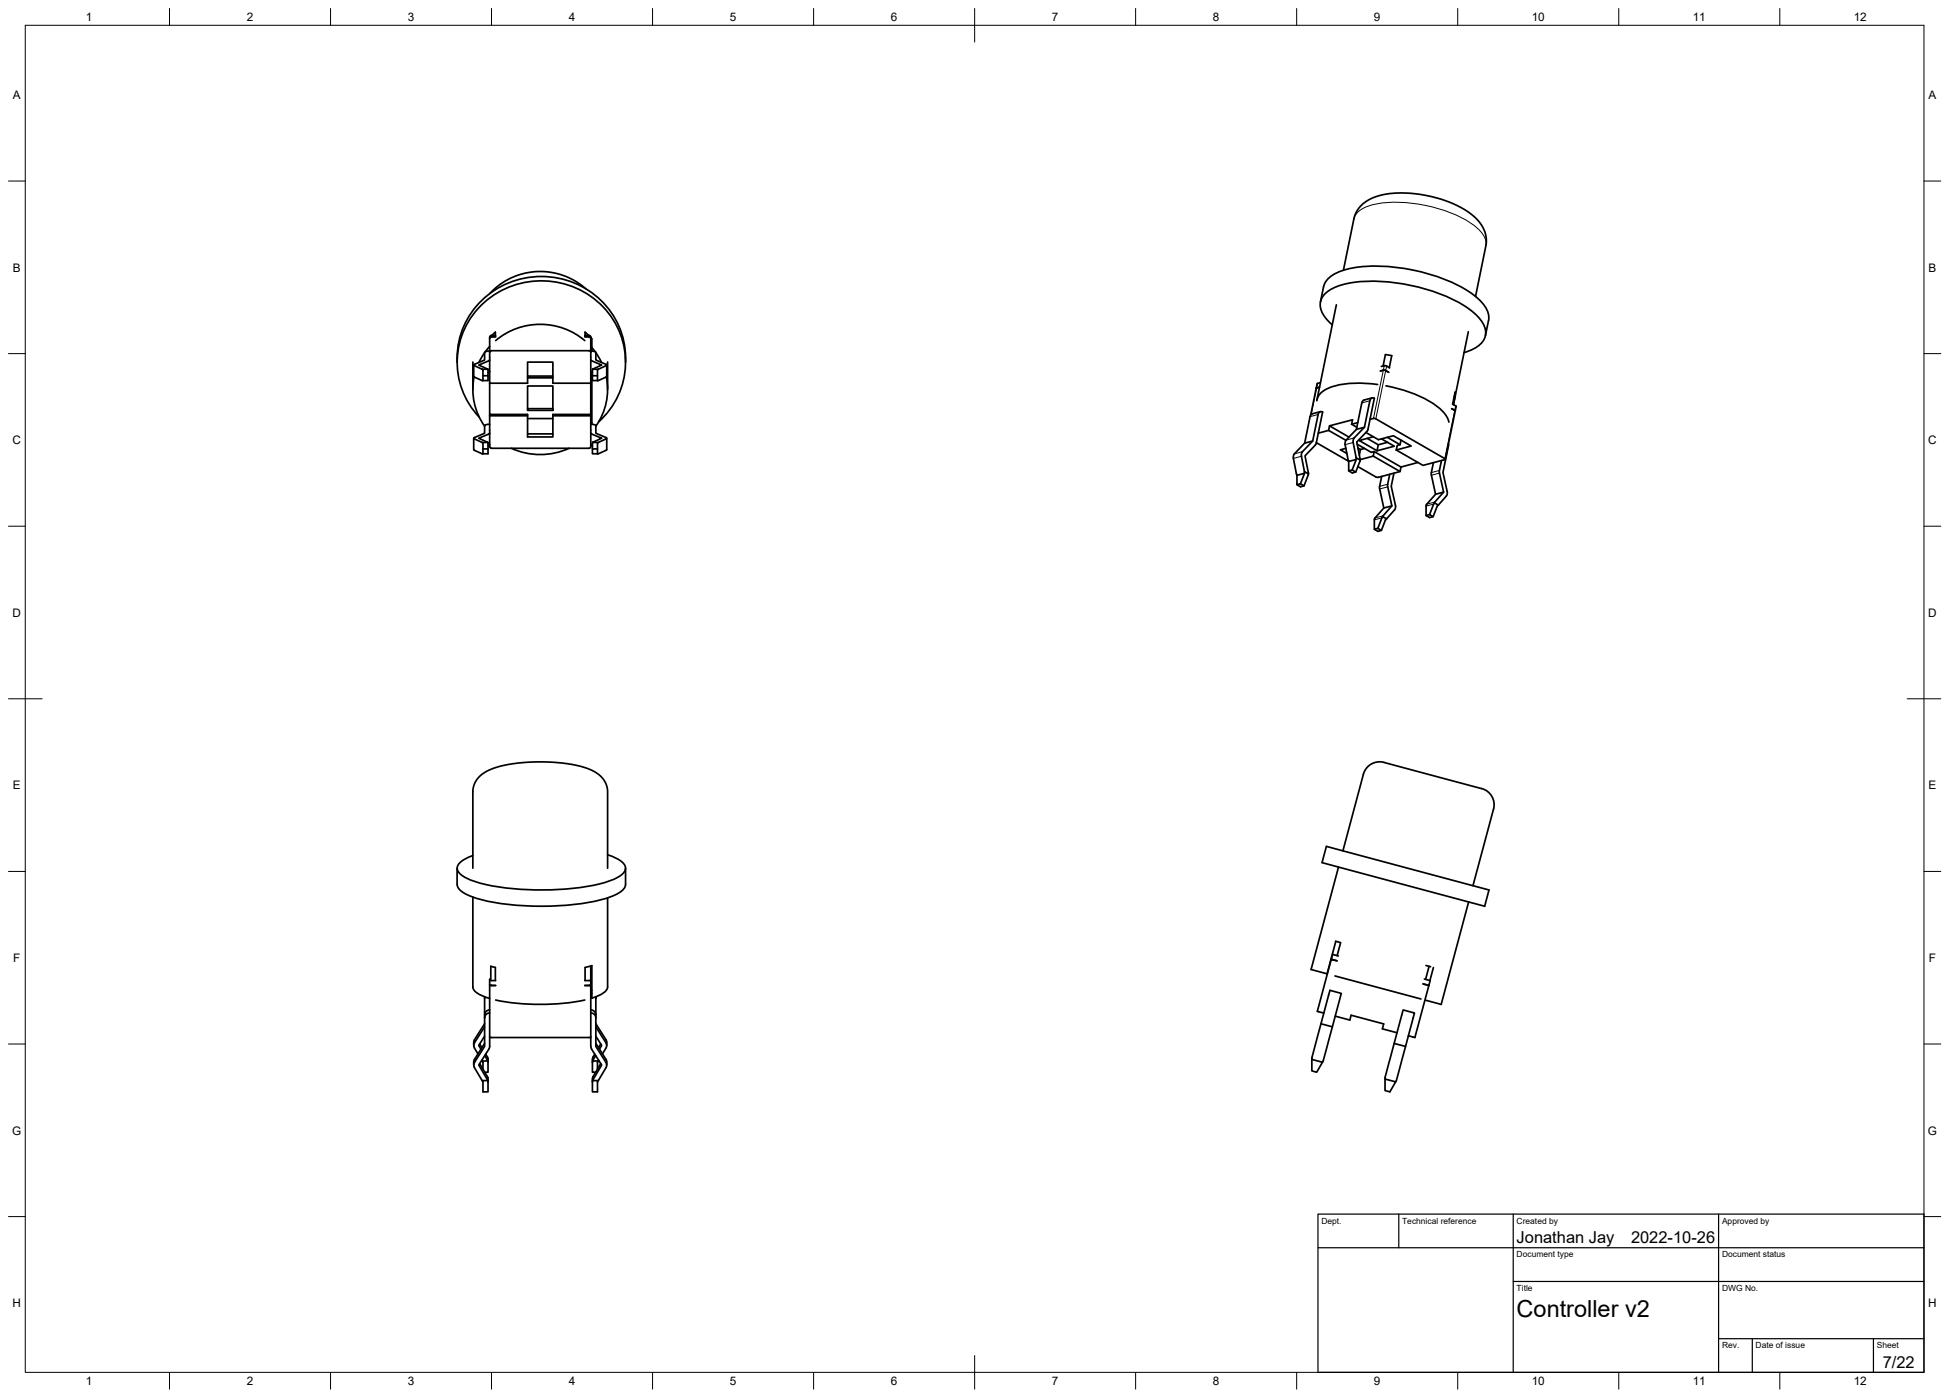
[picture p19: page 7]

Dept. | Technical reference | Created by Jonathan Jay 2022-10-26 | Approved by

Document type | Document status

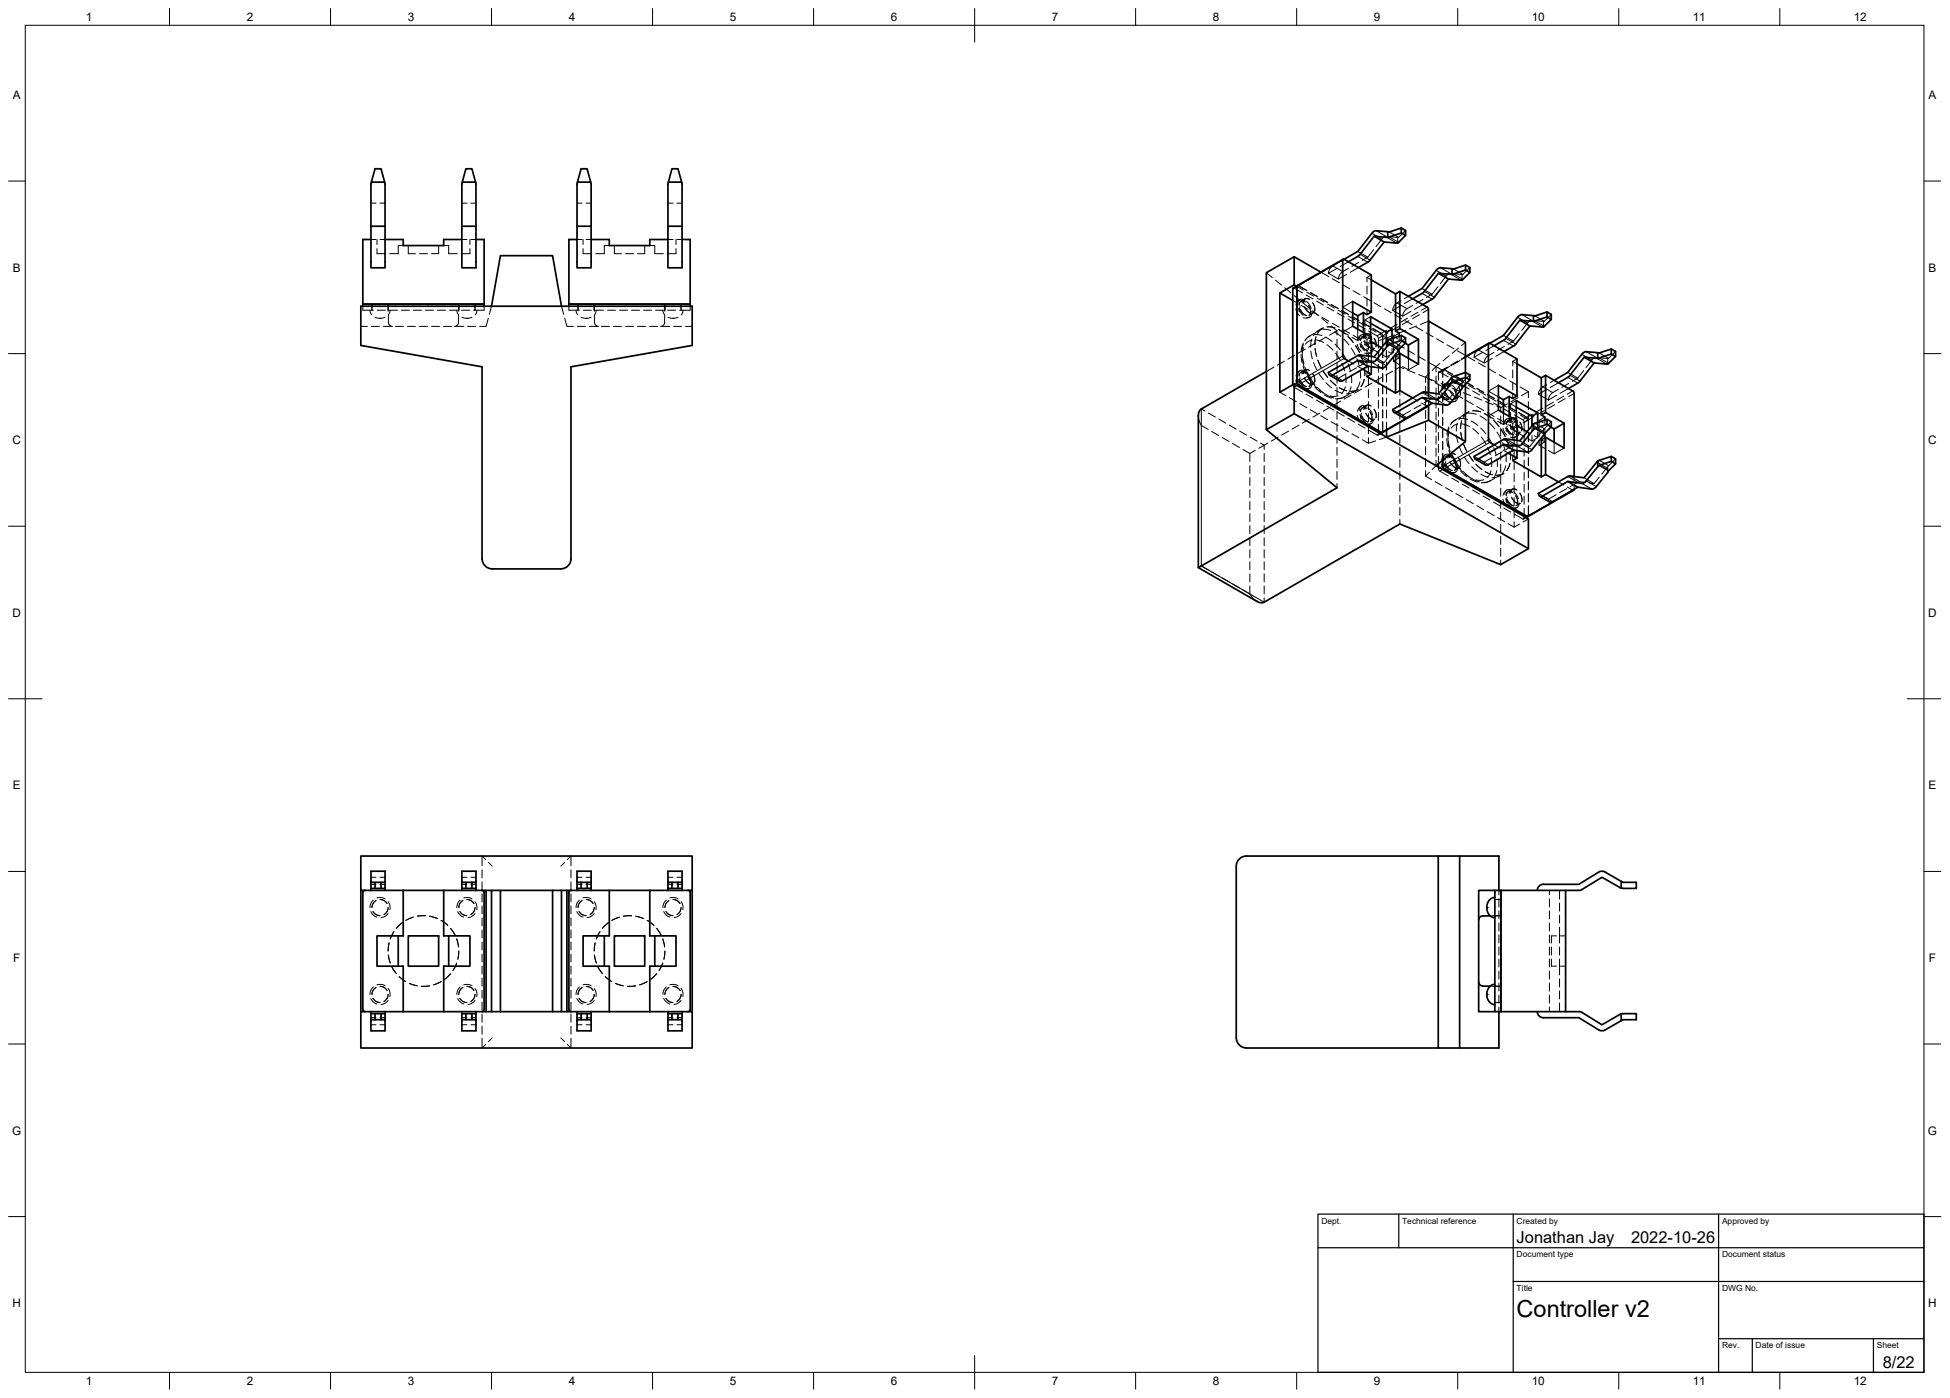
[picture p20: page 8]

Dept. | Technical reference | Created by Jonathan Jay 2022-10-26 | Approved by

Document type | Document status

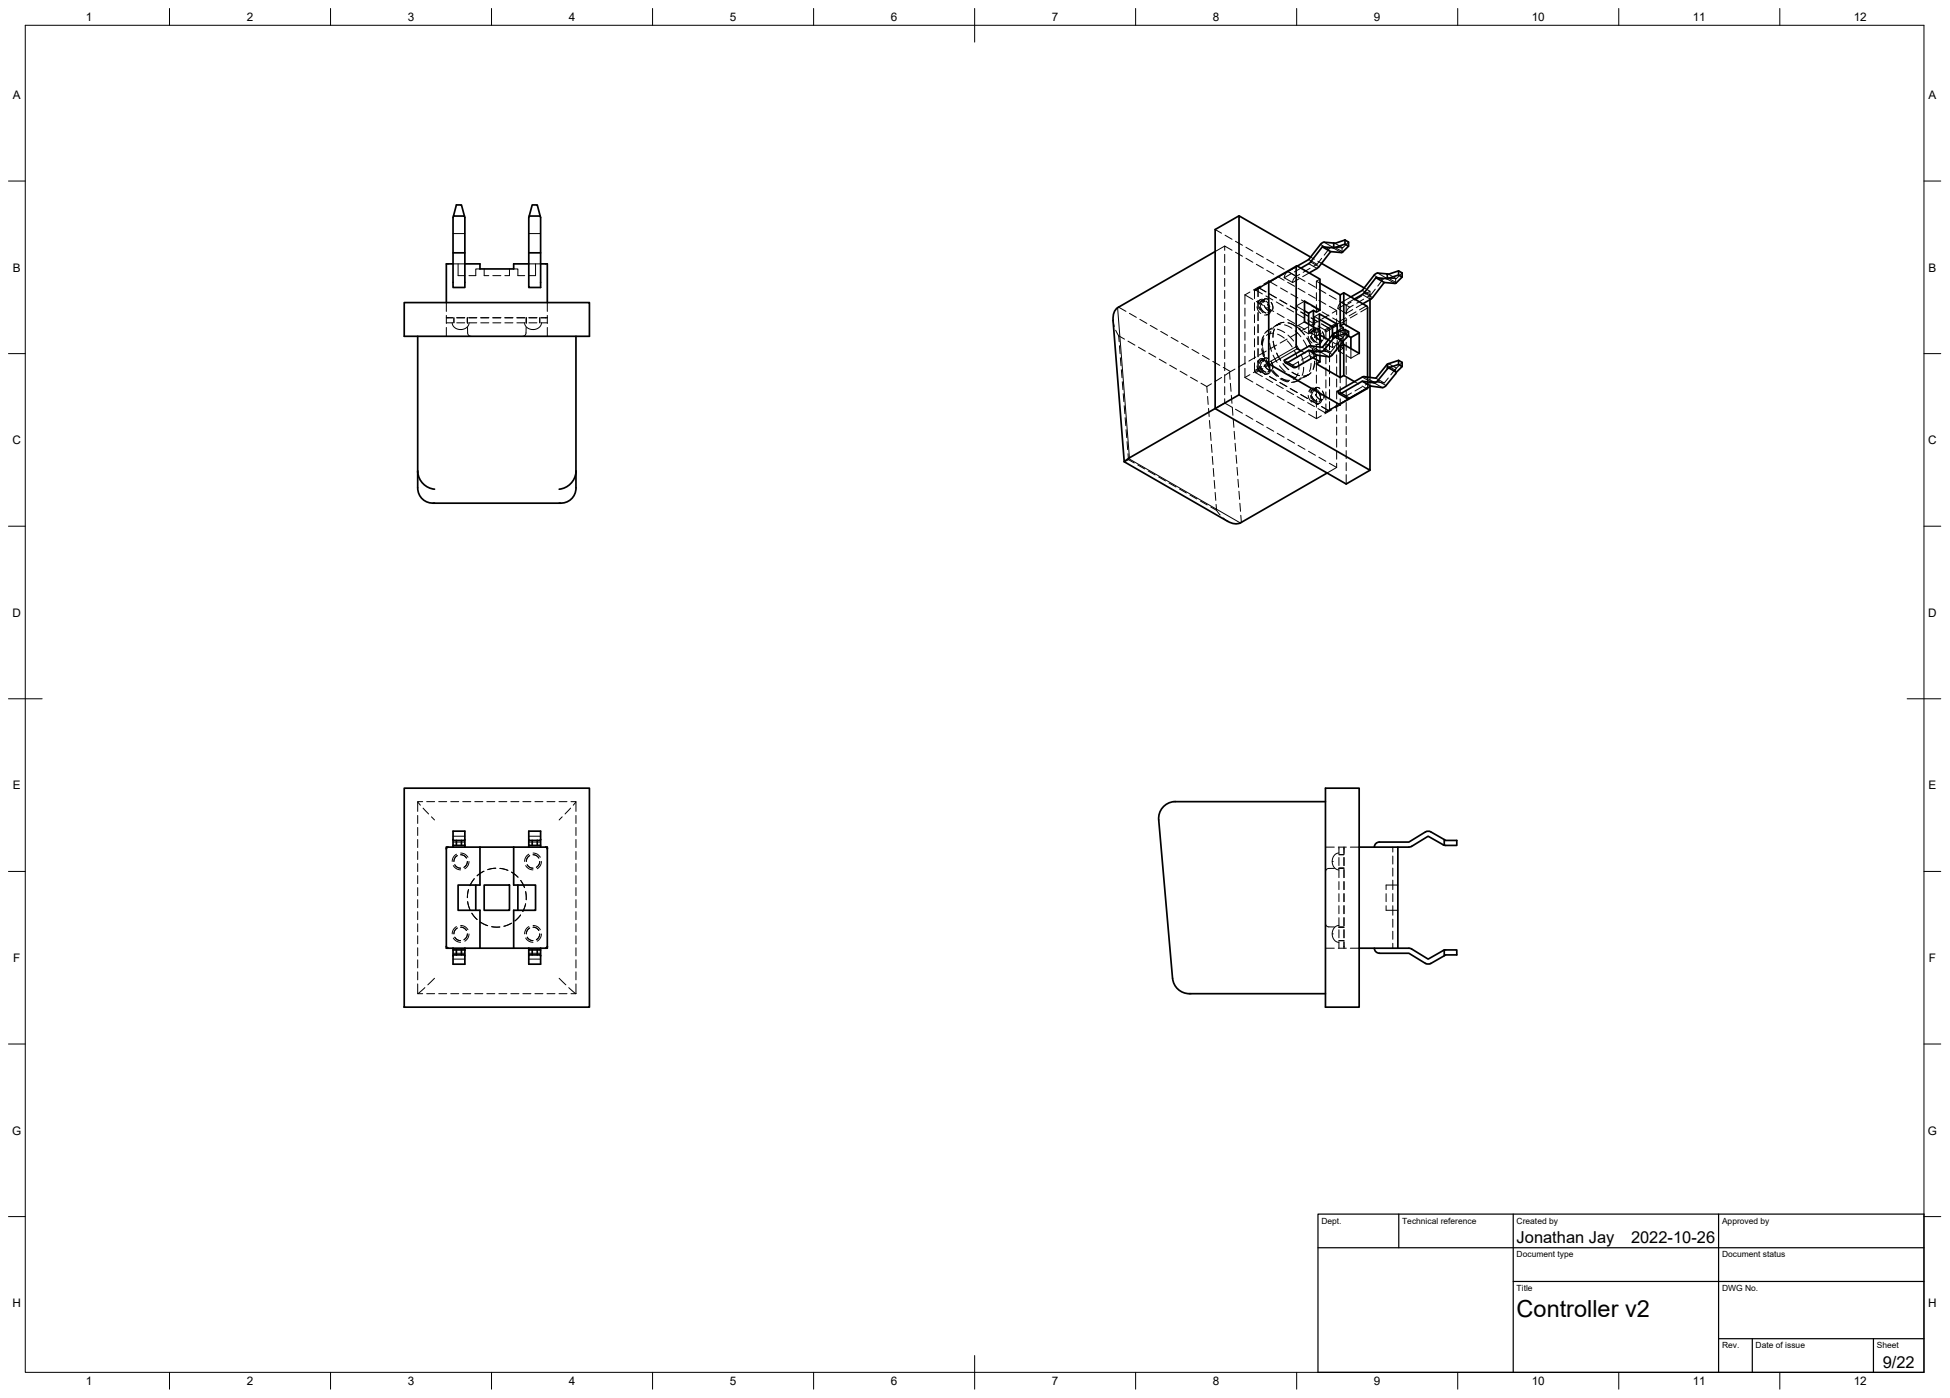
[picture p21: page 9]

Dept. | Technical reference | Created by Jonathan Jay 2022-10-26 | Approved by

Document type | Document status

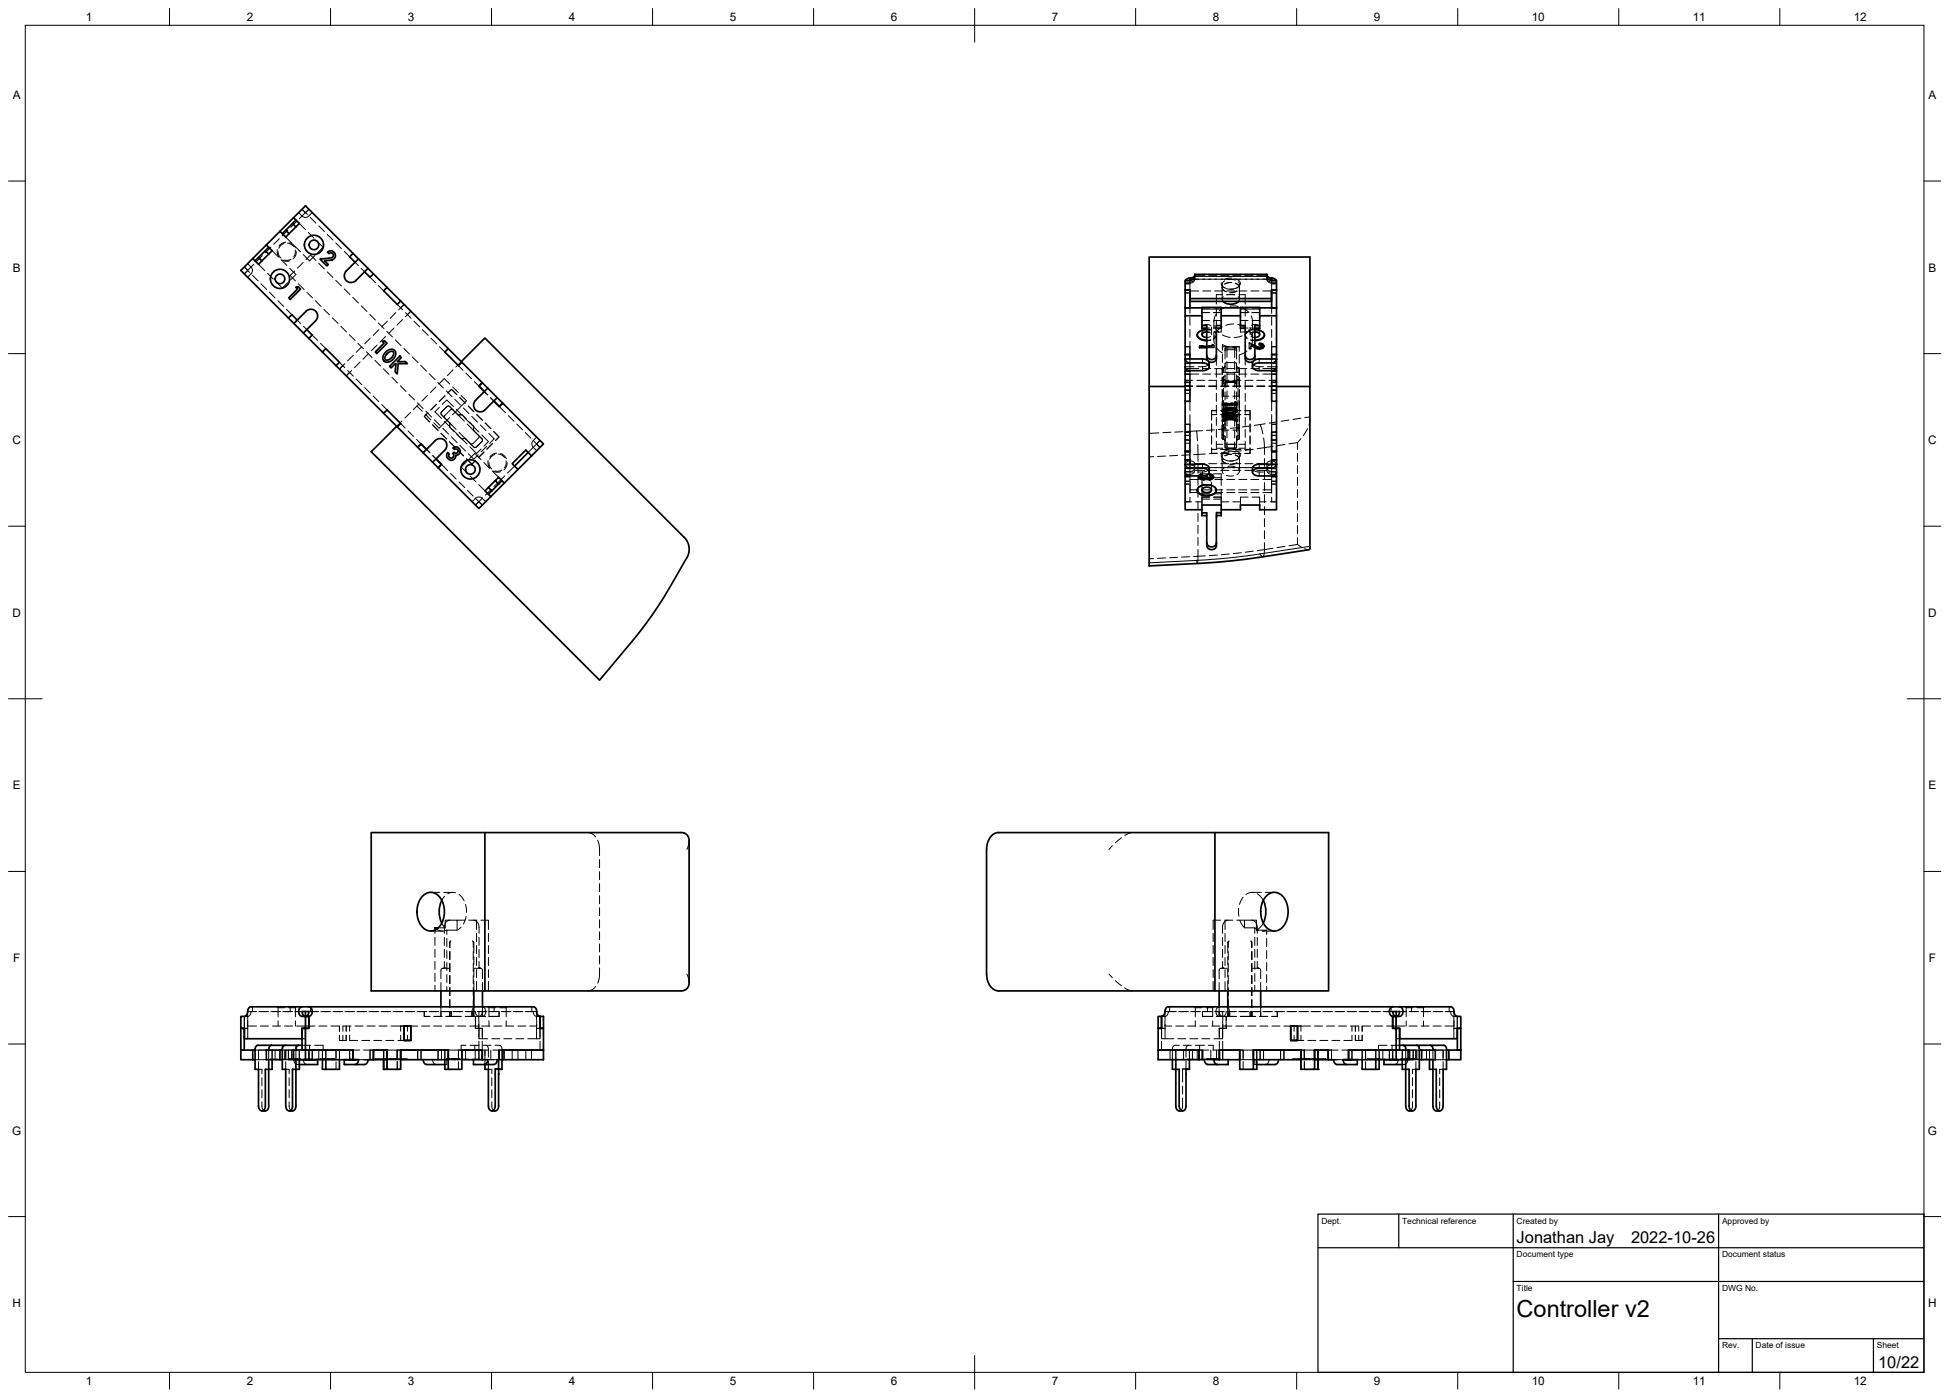
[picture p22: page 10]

Dept. | Technical reference | Created by Jonathan Jay 2022-10-26 | Approved by

Document type | Document status


Dept. | Technical reference | Created by Jonathan Jay 2022-10-26 | Approved by

Document type | Document status


Dept. | Technical reference | Created by Jonathan Jay 2022-10-26 | Approved by

Document type | Document status


Dept. | Technical reference | Created by Jonathan Jay 2022-10-26 | Approved by

Document type | Document status


Dept. | Technical reference | Created by Jonathan Jay 2022-10-26 | Approved by

Document type | Document status


Dept. | Technical reference | Created by Jonathan Jay 2022-10-26 | Approved by

Document type | Document status


Dept. | Technical reference | Created by Jonathan Jay 2022-10-26 | Approved by

Document type | Document status


Dept. | Technical reference | Created by Jonathan Jay 2022-10-26 | Approved by

Document type | Document status


Dept. | Technical reference | Created by Jonathan Jay 2022-10-26 | Approved by

Document type | Document status


Dept. | Technical reference | Created by Jonathan Jay 2022-10-26 | Approved by

Document type | Document status


Dept. | Technical reference | Created by Jonathan Jay 2022-10-26 | Approved by

Document type | Document status


Dept. | Technical reference | Created by Jonathan Jay 2022-10-26 | Approved by

Document type | Document status


Dept. | Technical reference | Created by Jonathan Jay 2022-10-26 | Approved by

Document type | Document status

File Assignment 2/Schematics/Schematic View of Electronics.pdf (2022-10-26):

A

1 | 2 | 3 | 4 | 5 | 6


Title: Accurate Epic Snaget

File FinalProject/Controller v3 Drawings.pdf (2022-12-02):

Title; DWG No.; Rev.; Date of issue; Sheet; Tact Holder; Controller v3

Dept. | Technical reference | Created by Jonathan Jay 2022-11-30 | Approved by

Document type Technical Drawing | Document status

Title; DWG No.; Controller v3; Jonathan Jay 6.2

Dept. | Technical reference | Created by 2022-11-30 | Approved by

Document type Technical Drawing | Document status

Title; DWG No.; Controller v3; Jonathan Jay 10 23

Dept. | Technical reference | Created by 2022-11-30 | Approved by

Document type Technical Drawing | Document status

Title; DWG No.; Controller v3; Jonathan Jay 35.5

Dept. | Technical reference | Created by 2022-11-30 | Approved by

Document type Technical Drawing | Document status

Title; DWG No.; Controller v3

Dept. | Technical reference | Created by Jonathan Jay 2022-11-30 | Approved by

Document type Technical Drawing | Document status

Title; DWG No.; Controller v3

Dept. | Technical reference | Created by Jonathan Jay 2022-11-30 | Approved by

Document type Technical Drawing | Document status

Title; DWG No.; Controller v3

Dept. | Technical reference | Created by Jonathan Jay 2022-11-30 | Approved by

Document type Technical Drawing | Document status

Title; DWG No.; Controller v3; Jonathan Jay 11.5

Dept. | Technical reference | Created by 2022-11-30 | Approved by

Document type Technical Drawing | Document status

Title; DWG No.; Controller v3

Dept. | Technical reference | Created by Jonathan Jay 2022-11-30 | Approved by

Document type Technical Drawing | Document status

Title; DWG No.; Controller v3; Jonathan Jay 14

Dept. | Technical reference | Created by 2022-11-30 | Approved by

Document type Technical Drawing | Document status

Title; DWG No.; Small Button; Controller v3

Dept. | Technical reference | Created by Jonathan Jay 2022-11-30 | Approved by

Document type Technical Drawing | Document status

Title; DWG No.; Controller v3

Dept. | Technical reference | Created by Jonathan Jay 2022-11-30 | Approved by

Document type Technical Drawing | Document status

Title; DWG No.; Controller v3

Part is too complex to get all
mesurements in on time (and visibly)

As such, it won't be complete

Dept. | Technical reference | Created by Jonathan Jay 2022-11-30 | Approved by

Document type Technical Drawing | Document status

Title; DWG No.; Controller v3

Part is too complex to get all
mesurements in on time (and visibly)

As such, it won't be complete

Dept. | Technical reference | Created by Jonathan Jay 2022-11-30 | Approved by

Document type Technical Drawing | Document status

Title; DWG No.; Controller v3

Part is too complex to get all
mesurements in on time (and visibly)

Fusion also dislikes angled faces, so
some circles can't be measured

As such, it won't be complete

Dept. | Technical reference | Created by Jonathan Jay 2022-11-30 | Approved by

Document type Technical Drawing | Document status

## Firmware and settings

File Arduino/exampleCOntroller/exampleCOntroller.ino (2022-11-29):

/*
 * This example turns the ESP32 into a Bluetooth LE gamepad that presses buttons and moves axis
 *
 * At the moment we are using the default settings, but they can be canged using a BleGamepadConfig instance as parameter for the begin function.
 *
 * Possible buttons are:
 * BUTTON_1 through to BUTTON_16
 * (16 buttons by default. Library can be configured to use up to 128)
 *
 * Possible DPAD/HAT switch position values are:
 * DPAD_CENTERED, DPAD_UP, DPAD_UP_RIGHT, DPAD_RIGHT, DPAD_DOWN_RIGHT, DPAD_DOWN, DPAD_DOWN_LEFT, DPAD_LEFT, DPAD_UP_LEFT
 * (or HAT_CENTERED, HAT_UP etc)
 *
 * bleGamepad.setAxes sets all axes at once. There are a few:
 * (x axis, y axis, z axis, rx axis, ry axis, rz axis, slider 1, slider 2)
 *
 * Library can also be configured to support up to 5 simulation controls
 * (rudder, throttle, accelerator, brake, steering), but they are not enabled by default.
 *
 * Library can also be configured to support different function buttons
 * (start, select, menu, home, back, volume increase, volume decrease, volume mute)
 * start and select are enabled by default
 */

#include <Arduino.h>
#include <BleGamepad.h>

#define LED 12

//4 face button pins (Or I guess back buttons in this case)
#define A_Button 13
#define B_Button 16 
#define X_Button 14
#define Y_Button 27

//Start and Select
#define Start_Button 33
#define Select_Button  32

//Shift Button
#define Shift_Button 04

//LB and RB
#define Left_Bumper 25
#define Right_Bumper 26

//Analog Stick
#define X_Stick 34//34 //INPUT ONLY GPIO PINS!!
#define Y_Stick 35//35 //INPUT ONLY GPIO PINS!!

#define Left_Trigger 36 //INPUT ONLY GPIO PINS!!
#define Right_Trigger 39 //INPUT ONLY GPIO PINS!!

#define ANALOG_FACTOR 8


const uint16_t faceButtons[] = {A_Button, B_Button, X_Button, Y_Button};
//A,B,X,Y,UP,DOWN,LEFT,RIGHT
const uint16_t allButtons[] = {BUTTON_1, BUTTON_2, BUTTON_3, BUTTON_4, HAT_DOWN, HAT_RIGHT, HAT_LEFT, HAT_UP};

BleGamepad bleGamepad("SoftWHERE Controller");

BleGamepadConfiguration bleGamepadConfig;

void setup()
{
    Serial.begin(115200);
    
    //Face (Back of device) Buttons
    pinMode(A_Button, INPUT_PULLUP);
    pinMode(B_Button,  INPUT_PULLUP);
    pinMode(X_Button,  INPUT_PULLUP);
    pinMode(Y_Button,  INPUT_PULLUP);

    // //Start/Select
    pinMode(Start_Button,  INPUT_PULLUP);
    pinMode(Select_Button,  INPUT_PULLUP);

    // //Shift button
    pinMode(Shift_Button,  INPUT_PULLUP);
    
    // //Bumpers
    pinMode(Left_Bumper,  INPUT);
    pinMode(Right_Bumper,  INPUT);    

    pinMode(X_Stick, INPUT);
    pinMode(Y_Stick, INPUT);
    pinMode(Left_Trigger, INPUT);
    pinMode(Right_Trigger, INPUT); 
    pinMode(LED, OUTPUT);   
  
    bleGamepadConfig.setAxesMin(0x8001); // -32767 --> int16_t - 16 bit signed integer - Can be in decimal or hexadecimal  
    bleGamepadConfig.setAxesMax(0x7FFF); // 32767 --> int16_t - 16 bit signed integer - Can be in decimal or hexadecimal
    bleGamepadConfig.setControllerType(CONTROLLER_TYPE_GAMEPAD);    
    bleGamepadConfig.setHatSwitchCount(1);  


    Serial.println("Starting BLE work!");
    bleGamepad.begin(&bleGamepadConfig);
    // The default bleGamepad.begin() above enables 16 buttons, all axes, one hat, and no simulation controls or special buttons
}
void loop()
{
  //LOW MEANS BUTTON PRESSED, HIGH MEANS BUTTON RELEASED

    if (bleGamepad.isConnected())
    {      
      //float stick[4] = {}; 
      float stick[4] = {analogRead(X_Stick), analogRead(Y_Stick), analogRead(Left_Trigger), analogRead(Right_Trigger)};
      uint8_t shift = digitalRead(Shift_Button); 
      //uint8_t shift = 0; 
      ////ANALOG STICK     
      //bleGamepad.setAxes(stick[0] * !shift * ANALOG_FACTOR, stick[1] * !shift * ANALOG_FACTOR, 0, stick[0] * shift * ANALOG_FACTOR, stick[1] * shift * ANALOG_FACTOR, 0, stick[2] * ANALOG_FACTOR, stick[3] * ANALOG_FACTOR);
      //bleGamepad.setAxes(stick[0] * !shift, stick[1] * !shift, 0, stick[0] * shift, stick[1] * shift, 0, 0, 0);
      bleGamepad.setAxes(2048, 2048, 2048, 2048, stick[2] * ANALOG_FACTOR, stick[3] * ANALOG_FACTOR, 0,0);    

      //Face Buttons and Dpad
      if(shift == HIGH)
      {
        digitalWrite(LED, LOW);                   
       for(int i = 0; i < 4; i++)
       {
          if(digitalRead(faceButtons[i]) == LOW) 
          {
            bleGamepad.press(allButtons[i]);
          }
          else
          {
            bleGamepad.release(allButtons[i]);
          }
       }
      }
      else
      {
        digitalWrite(LED, 255);
        for(int i = 0; i < 4; i++)
        { 
          if(digitalRead(faceButtons[i]) == LOW) 
          {
            bleGamepad.setHat1(allButtons[i + 4]);
          }
          else
          {
            bleGamepad.setHat1(HAT_CENTERED);
          }
        }
      }  
      


      // //Start and Select
      if(digitalRead(Start_Button) == HIGH)
      {
        bleGamepad.press(BUTTON_9);
      }  
      else
      {
        bleGamepad.release(BUTTON_9);        
      }
      if(digitalRead(Select_Button) == HIGH)
      {
        bleGamepad.press(BUTTON_10);
      }  
      else
      {
        bleGamepad.release(BUTTON_10);        
      } 





      if(digitalRead(Right_Bumper) == HIGH)
      {
        bleGamepad.press(BUTTON_5);
      }  
      else
      {
        bleGamepad.release(BUTTON_5);        
      }
      if(digitalRead(Left_Bumper) == HIGH)
      {
        bleGamepad.press(BUTTON_6);
      }  
      else
      {
        bleGamepad.release(BUTTON_6);        
      }   


        //  Serial.println("Press buttons 5, 16 and start. Move all enabled axes to max. Set DPAD (hat 1) to down right.");
        //  bleGamepad.press(BUTTON_5);
        //  bleGamepad.press(BUTTON_16);
        //  bleGamepad.pressStart();
        //  bleGamepad.setAxes(32767, 32767, 32767, 32767, 32767, 32767, 32767, 32767);
        //  bleGamepad.setHat1(HAT_DOWN_RIGHT); 
        //  // All axes, sliders, hats etc can also be set independently. See the IndividualAxes.ino example
        //  delay(500);

        //  Serial.println("Release button 5 and start. Move all axes to min. Set DPAD (hat 1) to centred.");
        //  bleGamepad.release(BUTTON_5);
        //  bleGamepad.releaseStart();
        //  bleGamepad.setHat1(HAT_CENTERED);
        //  bleGamepad.setAxes(0, 0, 0, 0, 0, 0, 0, 0);
        //  delay(500);      
    }
}

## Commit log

2022-10-26 Proper TinkerCAD Schematics
2022-11-05 Added first print files
    [Controller v2 seperated.3mf]
2022-11-11 Create Images of Device and Electronics
2022-11-11 Added 3D print and electronics images
